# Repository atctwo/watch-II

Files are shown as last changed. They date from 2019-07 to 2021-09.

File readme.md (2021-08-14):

# watch2

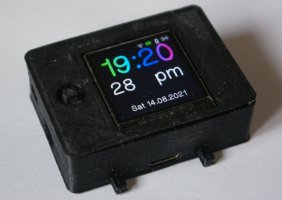
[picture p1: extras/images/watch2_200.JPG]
a picture of the watch


This repository contains the software and design files for my custom smartwatch thing.  The system is built on an ESP32, and the software is written in C++, using ESP-IDF and Arduino.  The software includes a few "apps", which are shown below.

The device uses a custom PCB that holds the ESP32, and all the other electronics that make the system work.  The PCB was designed in KiCad, and the enclosure for the device was made in OpenSCAD.

The system isn't as powerful as existing smartwatches, but it was a really great way for me to learn a lot of electronics and programming concepts and tools.  This isn't supposed to be a marketable product, but a proof of concept thing, and a way for me to develop my skills.  This repository is here as a kind of archive to show the level my skills are at at time of writing, and hopefully as a thing to look back on and learn from.

|  Watch Face |  Settings |  Calculator | Stopwatch |
|---|---|---|---|
|  Timer |  Alarms |  File Browser |  Notepad (read only) |
|  IR Remote |  Image Viewer |  Weather |  Wikipedia |
|  Quiz |  Music Player |  Internet Radio |  BLE Remote |
|  Sensor Thing |  Tetris |  Snek 2 |  NES | 

# Project Structure

- `components` ESP-IDF components
- `design_files` KiCad files for the schematic and PCB
- `docs` documentation for the system (see `docs/readme.md` for more detail)
- `extras` other stuff like icons, data files, and pinout for the original breadboard prototype
- `main` where all the code lives
- `spiffs` data and images for the SPIFFS partition

# Build Instructions

These are some rough instructions for installing and flashing the software on to an ESP32 board.  These steps are mainly aimed for Linux systems.

1. make sure the latest commit of ESP-IDF is installed and setup (this software is currently using commit [1d7068e](https://github.com/espressif/esp-idf/tree/1d7068e4be430edd92bb63f2d922036dcf5c3cc1))
2. `git clone` this repository somewhere - `git clone https://github.com/atctwo/watch-II.git`
3. `cd` into the project directory
    - then run these commands:
    ```
    chmod +x install_libraries.sh
    ./install_libraries.sh
    ```
    - this script automatically clones all of the submodules that the system depends on, then makes any neccessary modifications
4. use `idf.py menuconfig` to tell ESP IDF the flash size of the ESP32 you are using
    - go to `Serial flasher config → Flash size` and select the right flash size (i've only created partition files for 8MB and 16MB at the minute)
    - go to `Partition table → Custom partition CSV file` and enter either `partitions_8mb.csv` or `partitions_16mb.csv`
5. to build the software, run `idf.py build`, and to write the built firmware to an ESP32 board, run `idf.py flash` (see the [ESP-IDF documentation](https://docs.espressif.com/projects/esp-idf/en/latest/esp32/api-guides/build-system.html#idf-py) for more detail on these commands)
6. next, flash an SPIFFS image to the device
    - to do that from the root of the repository, call one of these commands depending on what flash size your ESP32 has:
    ```bash
    # if you're using an 8 MB flash
    esptool.py --port /dev/ttyUSB0 write_flash 0x340000 spiffs/spiffs_8mb.bin  

    # if you're using a 16 MB flash
    esptool.py --port /dev/ttyUSB0 write_flash 0xE20000 spiffs/spiffs_16mb.bin  
    ```
    - more info on how SPIFFS is used can be found at [spiffs/readme.md](spiffs/readme.md)

# Credits
- *lots* of external libraries are used.  the details of these libraries can be found at [`docs/notes/libraries.md`](docs/notes/libraries.md)
- Most app icons are part of the [Papirus Icon Theme](https://github.com/PapirusDevelopmentTeam/papirus-icon-theme)
- Some icons made by [Icongeek26](https://www.flaticon.com/authors/icongeek26) from [Flaticon](https://www.flaticon.com/).
- The weather icons were designed by [Ian Amaral](https://dribbble.com/shots/5446697-Material-Design-inspired-weather-icons).
- The settings icon used in the IR Remote app is the one used by the Windows 10 Settings app.
- The icon used for the internet time button is [time zone](https://thenounproject.com/term/time-zone/2406165/) by Delwar Hossain from the Noun Project.
- The default font used is [HelvetiHand](https://www.dafont.com/helvetihand.font) by [Billy Snyder](https://www.dafont.com/billy-snyder.d4452).  It is modified slightly to add a ™ symbol.
- [Playing Cards](http://byronknoll.blogspot.com/2011/03/vector-playing-cards.html) by byronknoll

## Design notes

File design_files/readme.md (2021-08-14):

# watch 2 Design Files

This folder has a few different subfolders, explained below.  The schematic and PCB for the watch were designed using KiCad.  All of the development on the current form of the schematic + PCB takes place in the `watch2_board` folder.  The case for the watch was designed in OpenSCAD, and was designed to be 3D printed.  The rest of the folders are kept for archival purposes.

- `projects_are_a_bad_idea` an old 1.27mm pitch ESP32 breakout board
- `watch2` an old proof-of-concept version of the watch2 board design 
- `watch2_board` the current version of the board design
- `watch2_case` the case for the watch

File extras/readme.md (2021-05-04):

# Extras

- `icons` where most of the system icons are kept.  the actual code loads the icons from SPIFFS.  the icons used to generate the SPIFFS image are stored under `/spiffs/data`, meaning that this folder might not be completely up-to-date (or well organised)
- `images` some test images that were used at one point
- `i2s mic samples` and `i2s mic samples scaled` i can't remember what these were used for
- `imageconverter.py` a python script to convert a image (eg: png, jpg) to an RGB565 array for drawing to a TFT (most of the system icons are now loaded from SPIFFS as pngs)
- `ir.json` sample IR Remote profile for the IR Remote app
- `pinout.txt` a really old pinout for the original breadboard prototype
- `pinout.xlsx` a much more up to date pinout for the original breadboard prototype
- `Setup_watch2.h` setup file for TFT_eSPI (this is installed automatically by `install_libraries.sh`)

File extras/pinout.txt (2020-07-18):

GPIO	Direction	Usage
0	in		bootstrap pin / screenshot
1	out		tx
2	out		led pin
3	in		rx
4	out		sd chip select
5	out		tft chip select
6			internal spi flash
7			internal spi flash
8			internal spi flash
9			internal spi flash
10			internal spi flash
11			internal spi flash
12	out		ir pin
13	out		torch
14	out		tft backlight
15			<free>
16	in		internal spi ram / ir receive pin
17			internal spi ram
18	out		vspi clk
19	in		vspi miso
20			nc
21	out		vspi rst
22	out		tft dc
23	out		vspi mosi
24			nc
25	out		i2s dout
26	out		i2s lrc
27	out		i2s clock
28			nc
29			nc
30			nc
31			nc
32	in		dpad left
33	in		dpad up
34	in only		battery divider
35	in only		dpad right
36	in only		dpad enter
37			nc
38			nc
39	in only		dpad down

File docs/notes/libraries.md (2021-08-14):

# watch2 libraries

watch 2 depends on lots of different code libraries.  Most of them are Arduino or C/C++ libraries that are included as Git Submodules, although some of them are built into the Arduino ESP32 core (which is included as an ESP-IDF component).  While most libraries will work fine without any modification, some libraries have to be tweaked a bit for watch 2 to be able to work with them.  This page lists each of the libraries that watch2 depends on, and what modifications have to be made.

Most of the required libraries are `#include`d in `main/src/watch2.h`, although libraries that are only required by one app will probably only be `#include`d in the code for that app.

To automatically install and set up each of the libraries, and the Arduino ESP32 Core, you can use the script included in the root of the repository called `install_libraries.sh`.  This will update the submodules, and copy and modify files of libraries that need to be modified.  You can manually update the repository's submodules by running `git submodule update --recursive --init` in the root of the repository.

## Libraries

### STD and STL libraries
These are included as part of the compiler, so you don't have to provide these.  They are just listed here for completion.
- `stdio.h`
- `stdint.h`
- `time.h`
- `sys/time.h`
- `sys/cdefs.h`
- `string`
- `algorithm`
- `functional`
- `stack`
- `map` and `unordered_map`

### built in to ESP-IDF and the Arduino ESP32 Core
These libraries are either part of the ESP-IDF SDK (and thus don't need manually installed), or are part of the Arduino ESP32 Core (which does need installed, but it's included as a submodule, so it will be installed when you run `git submodule update`).
- SPI library (`SPI.h`)
- I2C library (`Wire.h`)
- ESP32 FS library (`FS.h`)
- SD library (`SD.h`)
- WiFi library (`WiFi.h`)
- Wifi secure client library (`WiFiClientSecure.h`)
- HTTP client library (`HTTPClient.h`)
- ESP32 Preferences library (`Preferences.h`)
- [cJSON](https://github.com/DaveGamble/cJSON) (not Arduino or ESP32 specific, but bundled with the ESP32 core)

### external libraries
You will have to install these libraries yourself, although they are included as Git submodules to make installation really easy.
- [TFT_eSPI](https://github.com/Bodmer/TFT_eSPI) by Bodmer
- [JC_Button](https://github.com/JChristensen/JC_Button) by JChristensen
- [Time](https://github.com/PaulStoffregen/Time) by Paul Stoffregen
- [TimeAlarms](https://github.com/PaulStoffregen/TimeAlarms) by Paul Stoffregen
- [ESP32 BLE Keyboard](https://github.com/T-vK/ESP32-BLE-Keyboard) by T-vK
- [ESP32-audioI2S](https://github.com/schreibfaul1/ESP32-audioI2S) by schreibfaul1
- [Adafruit BusIO](https://github.com/adafruit/Adafruit_BusIO) by Adafruit
- [Adafruit MCP23008](https://github.com/adafruit/Adafruit-MCP23008-library) by Adafruit
- [Adafruit LC709203F](https://github.com/adafruit/Adafruit_LC709203F) by Adafruit
- [Adafruit MCP9808](https://github.com/adafruit/Adafruit_MCP9808_Library) by Adafruit
- [Adafruit Unified Sensor Driver](https://github.com/adafruit/Adafruit_Sensor) by Adafruit
- [Adafruit SHTC3](https://github.com/adafruit/Adafruit_SHTC3) by Adafruit
- [csscolorparser](https://github.com/mapbox/css-color-parser-cpp) by Dean McNamee and Konstantin Käfer
- [gumbo-parser](https://github.com/google/gumbo-parser) by Google
- [tinyexpr](https://github.com/codeplea/tinyexpr) by codeplea
- [tinywav](https://github.com/mhroth/tinywav) by mhroth
- [libtris](https://github.com/atctwo/libtris) by atctwo
- [snake-game](https://github.com/atctwo/snake-game) by atctwo

### included with the repository
You won't have to manually install these libraries, because they are directly included with the repository.

The system uses two of nothings' stb libraries (https://github.com/nothings/stb), specifically stb_image.h and stb_image_resize.h.  stb_image was modified slightly to shut the compiler up.  The modified version is included with the source.

HTML character decoding is performed by the [`entities` library](https://stackoverflow.com/a/1082191), by cggaertner.

The NES Emulator is built around [agnes](https://github.com/kgabis/agnes).

The system uses a fork of [IRremote](https://github.com/ExploreEmbedded/Arduino-IRremote) that adds ESP32 send support that was never merged back into the original IRremote.  This fork has been modified to allow the IR receiver to be disabled.  The original IRremote has now added ESP32 send support, and IR receiver disable support, although I have yet to get ESP32 IR send working with the system.

A modified version of [ds1337](https://github.com/richard-clark/ds1337) by Richard Clark is included with the repository.

## Modifications

These are the modifications you need to make to some of the libraries to get watch2 to work with them.  The system will still compile if you don't perform these modifications, but you will need to modify them to match with the exact hardware that you are using.  The modifications listed below are specific to the watch 2 hardware that the system is being developed for, so if you are trying to get watch 2 running on a different board, you should see the documentation for the config files, and configure them to work with the hardware you are using.

Most of these modifications are made automatically by `install_libraries.sh`

### Time

The file `Time.h` was removed to avoid conflicts with the STD library `time.h`.

### Arduino-IRremote

The system uses a fork of IRRemote that adds ESP32 support (https://github.com/ExploreEmbedded/Arduino-IRremote).  Because this fork is included directly in the repository, and not as a submodule, you don't have to make these changes yourself (but they are listed here for completion).  

In the file boarddefs.h, the value of TIMER_PWM_PIN (line 565) was changed from 5 to 4, and the value of TIMER_CHANNEL (line 563) was changed from 1 to 0.  The following method was added at line 159 of irRecv.cpp:
```c++
void IRrecv::disableIRIn() {

#ifdef ESP32
    timerEnd(timer);
    timerDetachInterrupt(timer);
#endif 

}
```
A method prototype was also added at line 180 of IRRemote.h:
```c++
171 class IRrecv
172 {
173 	public:
174 		IRrecv (int recvpin) ;
175 		IRrecv (int recvpin, int blinkpin);
176 
177 		void  blink13    (int blinkflag) ;
178 		int   decode     (decode_results *results) ;
179 		void  enableIRIn ( ) ;
180 		void  disableIRIn( ) ;
181 		bool  isIdle     ( ) ;
182 		void  resume     ( ) ;
```

### TFT_eSPI

The TFT screen is controlled using Bodmer's wonderful TFT_eSPI library (https://github.com/Bodmer/TFT_eSPI).  This library is configured using a User setup header file in the library's source directory.  The file is cloned in the extras folder of this repo (it's called "Setup_watch2.h").  To configure TFT_eSPI to use this setup file, 
1. copy `Setup_watch2.h` to `main/libraries/TFT_eSPI/User_Setups`
2. modify `main/libraries/TFT_eSPI/User_Setup_Select.h`:
    - uncomment `#include <User_Setup.h>` on line 22
    - add `#include <User_Setups/Setup_watch2.h>` on the line below
    - please make sure that only one User Setup is included in this file

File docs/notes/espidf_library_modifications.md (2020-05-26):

As part of the move to ESP-IDF, some libraries were modified to get the system to compile.  This is a list of the modifications made.

## ESP32 Core Wifi library (`components/arduino/libraries/WiFi`)

These modifications were taken from [this ESP32 Arduino issue](https://github.com/espressif/arduino-esp32/issues/3760#issuecomment-591145500).

### `components/arduino/libraries/WiFi/src/ETH.cpp`, line 196

change
```c++
ip_addr_t dns_ip = dns_getserver(dns_no);
return IPAddress(dns_ip.u_addr.ip4.addr);
```

to

```c++
const ip_addr_t * dns_ip = dns_getserver(dns_no);
return IPAddress(dns_ip->u_addr.ip4.addr);
```

### `components/arduino/libraries/WiFi/src/WiFiSTA.cpp`, line 491

change

```c++
ip_addr_t dns_ip = dns_getserver(dns_no);
return IPAddress(dns_ip.u_addr.ip4.addr);
```

to

```c++
const ip_addr_t * dns_ip = dns_getserver(dns_no);
return IPAddress(dns_ip->u_addr.ip4.addr);
```

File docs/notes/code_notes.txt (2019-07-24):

(1) Time
    During active mode operation, functions from TimeLib.h are used to conveniently handle the time.  These functions operate on an internal
    measure of time kept by the library, and don't touch the measure of time maintained by the ESP32.  This measure can be operated on using
    standard POSIX time functions from time.h and sys/time.h.  To ensure that the time is kept while sleeping, the time kept by TimeLib.h is
    used to set the time kept by the ESP32.  When the device goes to sleep, the ESP32 time is set to the TimeLib.h time, and when the device
    is woken up, the TimeLib.h time is set to the ESP32 time.  I know it's unneccessarily complicated, but shut up.

(2) Preferences
    User settings are stored in non-volatile storage (NVS) using the ESP32 library Preferences.  Some of these settings need to be accessed
    every iteration of the main loop (like timeout settings and theme colour settings).  It would be inefficient to access the settings from
    NVS every iteration, so global variables are used to keep copies of the setting values in RAM, allowing for faster access.  When the
    settings are changed, the global variables are set to the new values, and the NVS instances of the settings are updated.  When the
    system is turned on, the NVS settings are loaded, and are used to set the global variables.

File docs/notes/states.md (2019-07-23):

# watch II state system_states
watch II uses a state system to decide what "app" is currently being executed.  State 0 is in initalisation state, state 1 is the watch face, and state 2 is the state menu.  You don't see anything done by state 0, because it executes once, then changes to state 1.

## Adding system states
One way that you can add your own program to the system is to add your own state.  The other option is to write a Lua script.  If you decide to write a state, you get more control over the hardware, and probably more performance, but you have to recompile the system (which you don't have to do if you write a Lua script), and you have to write the state in C++ (specifically Arduino).

To write a state, open `watch2/states/user_states.cpp`.  You will notice that the file contains a function called `registerUserStates()`.  This function is called during system initialisation, so any code written inside this function is executed.  To add a state, you have to use a system function called `registerState()`.  Its parameters are described below:

```
int registerState(String stateName,
                  const std::function<void()> &stateFunc );

    stateName       The name of the state as shown on the state menu
    stateFunc       The function to be executed when this state is loaded

```
Whenever a state is chosen from the state menu, the state is switched, and the function attributed to that state is executed.  The function is executed in a loop until the state is changed.  So that you know when the state is being executed for the first time, you can use a global variable called `state_init`.  Normally this variable is set to 0 when the state function is being called for the first time, and is set to 1 for each call thereafter.  Note that what you write to the screen on the first call won't be displayed, but every subsequent call will.

You can write a function, and pass it as the argument stateFunc, or you can use a lambda.  Rather than writing a function, and giving it a name, and then passing it to `registerState()`, you can write a function as part of the call to `registerState()`.  This is shown below:

```

// define a function and pass it to registerState
void coolStateFunc()
{
    oled.setCursor(2, 2);
    oled.setTextColor(WHITE);
    oled.println("Hello from this function");
}
registerState("A Cool State, using a defined function", coolStateFunc);

// use a lambda
registerState("A Cool State, using a lambda", [](){
    oled.setCursor(2, 2);
    oled.setTextColor(WHITE);
    oled.println("Hello from this lambda");
});

```

You can read up on lambdas on many C++ tutorial websites.

## Changing states
To switch state, use the function `switchState()`.  It has one parameter, which is the state you want to switch to.  If you are returning to the main menu, switch to state number 2.

The state is specified by a global variable called `state`.  There is noting stopping you manually setting it, but that might be a bad idea.

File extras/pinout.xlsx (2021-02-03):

watch2 pinout guide
by atctwo
 |  |  |  |  |  | ESP32 WROVER
5 way navigation switch |  |  | GND |  | GND |  | GND |  | GND
 |  |  | VCC | I2S LRC | 26 |  | NC |  | 23 | MOSI
A (right) | Enter |  | EN | I2S BLK | 27 |  | NC |  | 22 | DC
 |  | wakeup | 36 | Torch / TMS | 14 |  | 4 | IR LED | 1 | TX
 |  |  | 39 | IR recv/TDI | 12 |  | 0 |  | 3 | RX
B (up) | D (down) |  | 34 |  | GND |  | 2 |  | 21 | reset
 |  | I2S DIN | 35 | SD CS / TCK | 13 |  | 15 | SCL | NC
 |  | SDA | 32 |  | 9 |  | 8 |  | 19 | MISO
C (left) | Common | TFT backlight | 33 |  | 10 |  | 7 |  | 18 | Clock
 |  | I2S DOUT | 25 |  | 11 |  | 6 |  | 5 | TFT CS
https://cdn-shop.adafruit.com/datasheets/SKQUCAA010-ALPS.pdf |  |  |  | GND |  |  |  |  | GP7 | supervisor shutdown
 |  |  |  | VCC |  |  |  |  | GP6
 |  |  |  | Bootstrapping pins |  |  |  |  | GP5
 |  |  |  | Internal SPI pins (don’t use) |  |  |  |  | GP4 | dpad left
 |  |  |  | I2C |  |  |  |  | GP3 | dpad down
 |  |  |  | I2S |  |  |  |  | GP2 | dpad enter
 |  |  |  | VSPI + TFT stuff |  |  |  |  | GP1 | dpad up
 |  |  |  | dpad pins |  |  |  |  | GP0 | dpad right
 |  |  |  | other peripherals |  |  |  |  | MCP23008
 |  |  |  | Serial
 |  |  |  | input only pins

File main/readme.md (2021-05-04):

# watch2 Source Code

Here is a brief description of how the code for watch2 is organised

- `main.cpp` contains the system initialisation code, main loop, and main entry point
- each of the `watch2_*.cpp` files contain the source code for handling a particular subsystem or related functions.  they share one big header file called `watch2.h`
    - `watch2_audio.cpp` contains functions for using the I2S audio subsystem
    - `watch2_battery.cpp` contains functions to query the battery fuel gauge
    - `watch2_bluetooth.cpp` contains functions to interface with the BLE subsystem
    - `watch2_dialogues.cpp` contains functions to draw a few interactive popup dialogues
    - `watch2_drawing.cpp` contains functions for drawing standard things like menus
    - `watch2_files.cpp` contains utility functions for talking to an SD card (these functions are designed to complement the functions in the Arduino SD Library)
    - `watch2_images.cpp` contains functions for decoding and drawing standard image formats (based on `stb_image.h`)
    - `watch2_system.cpp` contains some core system functions
    - `watch2_utility.cpp` contains some miscellaneous utility functions
    - `watch2_wifi.cpp` contains functions for talking to the WiFi subsystem
- the `states` directory contains source files for each of the system's states / apps
- the `libraries` folder contains most of the libraries the system depends on
- the `custom_fonts` folder contains fonts converted to header files that were used by early versions of the system
- the `icons` folder contains monochrome icons converted to byte arrays, used in some parts of the system (RGB565 icons are loaded as PNGs from SPIFFS)
- `root_store.cpp` contains a few TLS root certificates
- `regret.h` and `coolcrab.h` are unused image byte arrays

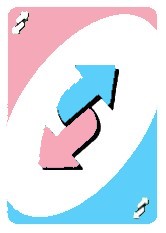
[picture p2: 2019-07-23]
extras/images/pls.jpg

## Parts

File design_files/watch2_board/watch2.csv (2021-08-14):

Reference | Value | Footprint | Datasheet | Availability | Description | MF | MP | Package | Price | AVAILABILITY | DESCRIPTION | PACKAGE | PRICE
BT1 | Battery_Cell | Connector_PinHeader_2.00mm:PinHeader_1x02_P2.00mm_Vertical | ~
U5 | MAX604 | Package_SO:SOIC-8-1EP_3.9x4.9mm_P1.27mm_EP2.29x3mm | http://datasheets.maximintegrated.com/en/ds/MAX603-MAX604.pdf
U2 | MCP73831-2-OT | Package_TO_SOT_SMD:SOT-23-5 | http://ww1.microchip.com/downloads/en/DeviceDoc/20001984g.pdf
D1 | LED | LED_SMD:LED_0805_2012Metric_Castellated | ~
R10 | 1k | Resistor_SMD:R_0805_2012Metric | ~
R9 | 2k | Resistor_SMD:R_0805_2012Metric | ~
R1 | 1k | Resistor_SMD:R_0805_2012Metric | ~
R6 | 1k | Resistor_SMD:R_0805_2012Metric | ~
SW1 | SW_Push | Button_Switch_SMD:SW_SPST_EVQP2 | ~
SW2 | SW_Push | Button_Switch_SMD:SW_SPST_EVQP2 | ~
R7 | 5k1 | Resistor_SMD:R_0805_2012Metric | ~
J1 | USB_C_Receptacle_USB2.0 | Alice's Library:JAE_DX07S016JA1R1500 | https://www.usb.org/sites/default/files/documents/usb_type-c.zip
R8 | 5k1 | Resistor_SMD:R_0805_2012Metric | ~
U4 | MAX16150AUT+T | Package_TO_SOT_SMD:SOT-23-6
U3 | MAX17043G+U | Package_DFN_QFN:DFN-8-1EP_3x2mm_P0.5mm_EP1.7x1.4mm
Q1 | Q_NPN_BCE | Package_TO_SOT_SMD:SOT-23 | ~
R14 | 1k | Resistor_SMD:R_0805_2012Metric | ~
R22 | 1k | Resistor_SMD:R_0805_2012Metric | ~
R5 | 27R | Resistor_SMD:R_0805_2012Metric | ~
R4 | 27R | Resistor_SMD:R_0805_2012Metric | ~
R18 | 1k | Resistor_SMD:R_0805_2012Metric | ~
R17 | 1k | Resistor_SMD:R_0805_2012Metric | ~
D3 | RX | LED_SMD:LED_0805_2012Metric_Castellated | ~
D2 | TX | LED_SMD:LED_0805_2012Metric_Castellated | ~
U1 | FT230XS | Package_SO:SSOP-16_3.9x4.9mm_P0.635mm | https://www.ftdichip.com/Support/Documents/DataSheets/ICs/DS_FT230X.pdf
J5 | Conn_01x03_Male | Connector_PinHeader_2.54mm:PinHeader_1x03_P2.54mm_Vertical | ~
R11 | R | Resistor_SMD:R_0805_2012Metric | ~
R12 | R | Resistor_SMD:R_0805_2012Metric | ~
R13 | R | Resistor_SMD:R_0805_2012Metric | ~
J4 | Conn_01x03_Male | Connector_PinHeader_2.54mm:PinHeader_1x03_P2.54mm_Vertical | ~
R19 | R | Resistor_SMD:R_0805_2012Metric | ~
R20 | R | Resistor_SMD:R_0805_2012Metric | ~
R2 | 4k7 | Resistor_SMD:R_0805_2012Metric | ~
R3 | 4k7 | Resistor_SMD:R_0805_2012Metric | ~
R15 | 1k | Resistor_SMD:R_0805_2012Metric | ~
R16 | 180R | Resistor_SMD:R_0805_2012Metric | ~
R23 | 4k7 | Resistor_SMD:R_0805_2012Metric | ~
R21 | 4k1 | Resistor_SMD:R_0805_2012Metric | ~
C3 | 10nF | Capacitor_SMD:C_0805_2012Metric | ~
C2 | 10uF | Capacitor_SMD:C_0805_2012Metric | ~
J2 | STEMMA QT | Connector_JST:JST_SH_SM04B-SRSS-TB_1x04-1MP_P1.00mm_Horizontal | ~
U7 | ESP32-WROVER | Alice's Library:ESP32-WROVER
J6 | TFT Connector | Connector_PinHeader_2.54mm:PinHeader_1x11_P2.54mm_Vertical | ~
U8 | MAX98357AETE+T | Package_DFN_QFN:QFN-16-1EP_3x3mm_P0.5mm_EP1.7x1.7mm |  | Unavailable | Audio Amp Speaker 1-CH Mono Class-D 16-Pin TQFN EP T/R | Maxim Integrated | MAX98357AETE+T | TQFN-16 Maxim | None
R24 | 680k | Resistor_SMD:R_0805_2012Metric | ~
D4 | LED_TORCH | Alice's Library:MLCAWT-A1-0000-000XE1 | ~
J8 | Torch Connector (daughter board) | Connector_PinHeader_2.54mm:PinHeader_1x02_P2.54mm_Vertical | ~
D5 | LED_IR | Alice's Library:SOD4223X290N | ~
R28 | 100R | Resistor_SMD:R_1812_4532Metric | ~
R31 | 100R | Resistor_SMD:R_1812_4532Metric | ~
LS1 | Speaker | Alice's Library:XDCR_CMT-7525-80-SMT-TR | ~
U9 | TSOP38238 | OptoDevice:Vishay_MINICAST-3Pin | http://www.vishay.com/docs/82491/tsop382.pdf
R25 | 100k | Resistor_SMD:R_0805_2012Metric | ~
R26 | 100k | Resistor_SMD:R_0805_2012Metric | ~
J3 | UART Connector | Connector_PinHeader_1.27mm:PinHeader_1x03_P1.27mm_Vertical | ~
MK1 | SPH0645LM4H-B | Alice's Library:MIC_SPH0645LM4H-B |  |  |  | Knowles | SPH0645LM4H-B |  |  | Unavailable | Mic Mems Digital I2s Omni -26db | SIP-7 Bourns | None
R27 | 10k | Resistor_SMD:R_0805_2012Metric | ~
R29 | 68R | Resistor_SMD:R_0805_2012Metric | ~
C4 | 10uF | Capacitor_SMD:C_0805_2012Metric | ~
C1 | 0.1uF | Capacitor_SMD:C_0805_2012Metric | ~
C5 | 0.1uF | Capacitor_SMD:C_0805_2012Metric | ~
C7 | 0.1uF | Capacitor_SMD:C_0805_2012Metric | ~
C8 | 0.1uF | Capacitor_SMD:C_0805_2012Metric | ~
Q3 | Q_NPN_BCE | Package_TO_SOT_SMD:SOT-23 | ~
R30 | 1k | Resistor_SMD:R_0805_2012Metric | ~
J7 | Torch Connector (main board) | Connector_PinHeader_2.54mm:PinHeader_1x02_P2.54mm_Vertical | ~
Q2 | Q_NPN_BCE | Package_TO_SOT_SMD:SOT-23 | ~
C6 | 0.1uF | Capacitor_SMD:C_0805_2012Metric | ~
U6 | MCP23008-xSS | Package_SO:SSOP-20_5.3x7.2mm_P0.65mm | http://ww1.microchip.com/downloads/en/DeviceDoc/MCP23008-MCP23S08-Data-Sheet-20001919F.pdf
R32 | 1k | Resistor_SMD:R_0805_2012Metric | ~

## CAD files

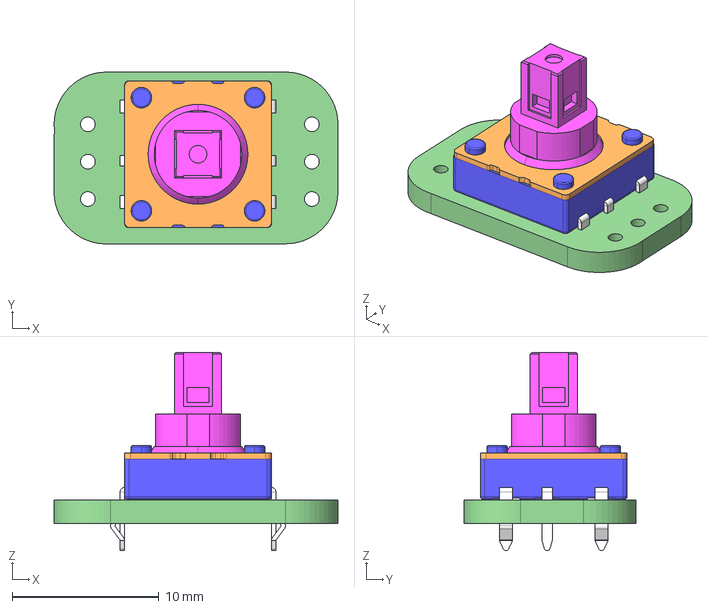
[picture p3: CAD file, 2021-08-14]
design_files/watch2_case/alps-switch.step
19.3 x 11.7 x 13.5 mm

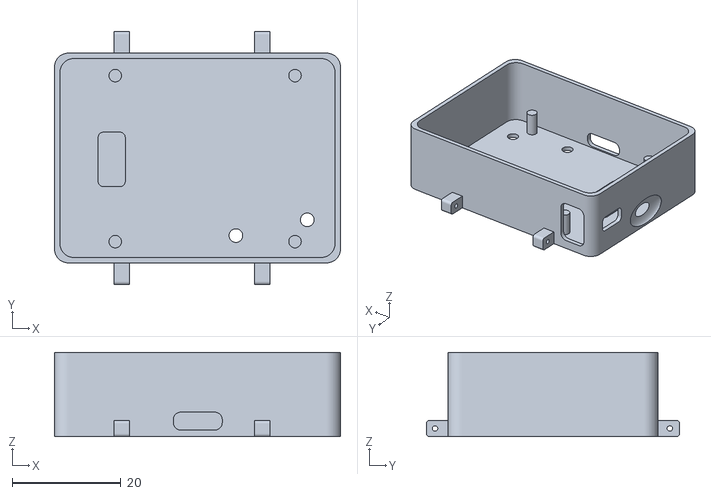
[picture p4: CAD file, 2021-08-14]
design_files/watch2_case/renders/v1-base-3.stl
52.5 x 46.5 x 15.5

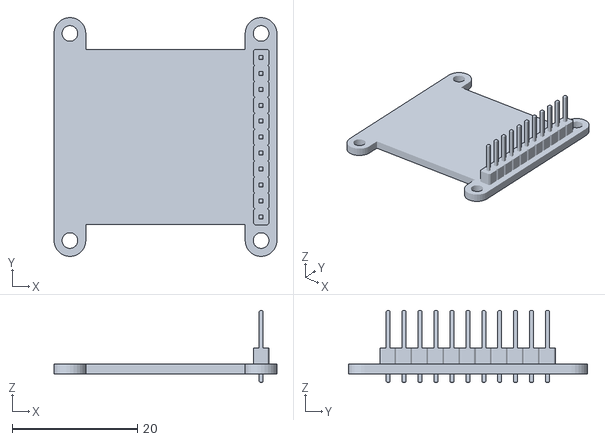
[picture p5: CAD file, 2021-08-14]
design_files/watch2_case/adafruit_1.3_tft.stl
35.6 x 38.1 x 11.5

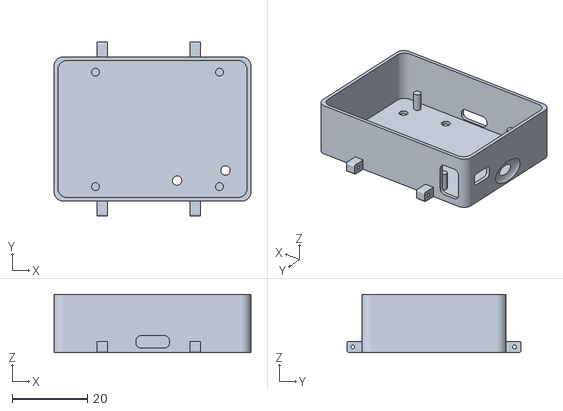
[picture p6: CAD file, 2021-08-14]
design_files/watch2_case/renders/v1-base-2.stl
52.5 x 46.5 x 15.5

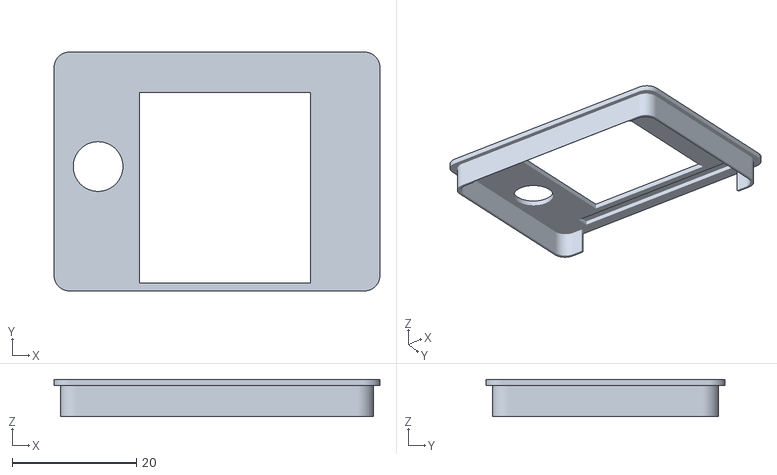
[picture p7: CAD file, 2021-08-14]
design_files/watch2_case/renders/v1-lid-3.stl
52.5 x 38.5 x 6.00

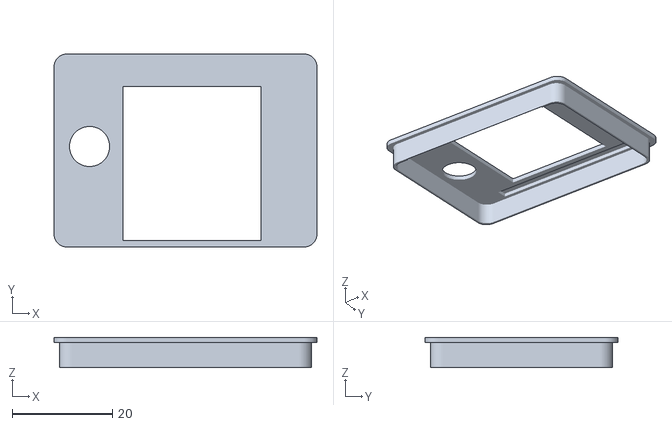
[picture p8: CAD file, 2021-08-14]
design_files/watch2_case/renders/v1-lid-3.1.stl
52.5 x 38.5 x 6.00

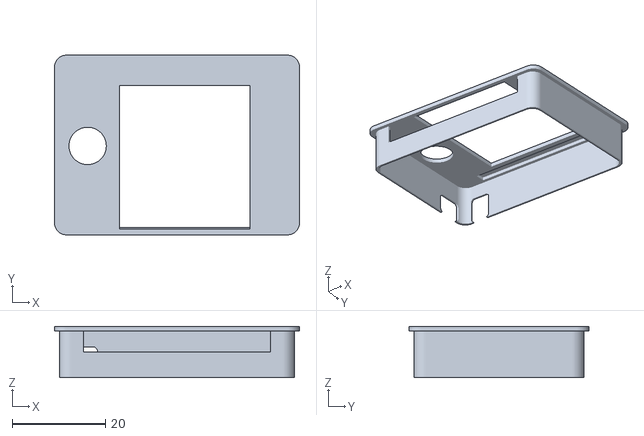
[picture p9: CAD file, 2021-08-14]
design_files/watch2_case/renders/v1.2-lid-1.stl
52.5 x 38.5 x 11.0

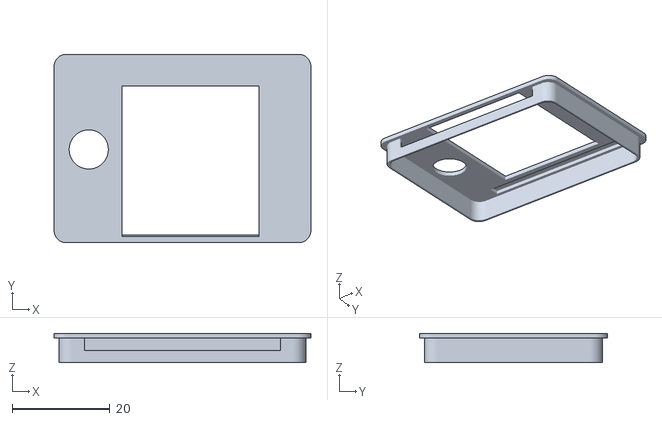
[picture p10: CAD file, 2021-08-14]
design_files/watch2_case/renders/v1-lid-3.3.stl
52.5 x 38.5 x 6.00

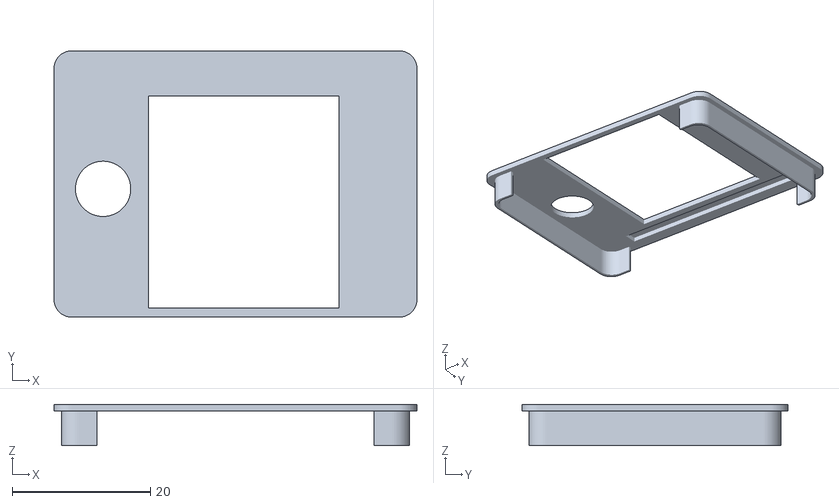
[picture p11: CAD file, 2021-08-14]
design_files/watch2_case/renders/v1-lid-2.stl
52.5 x 38.5 x 6.00

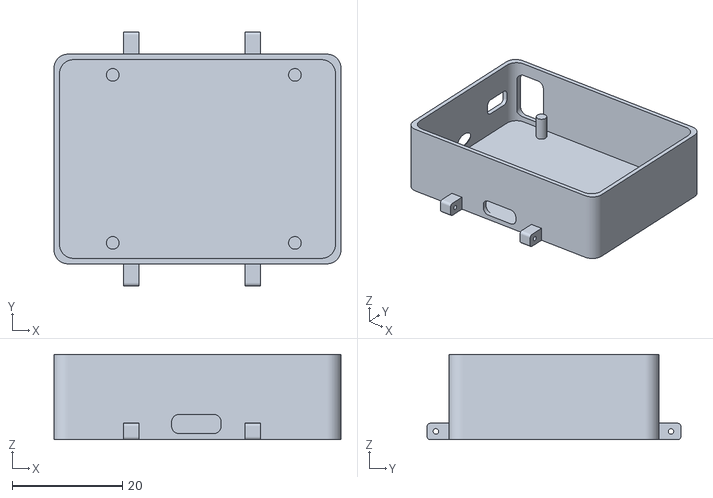
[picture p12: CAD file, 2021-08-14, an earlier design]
design_files/watch2_case/renders/v1-base-1.stl
52.0 x 46.0 x 15.5

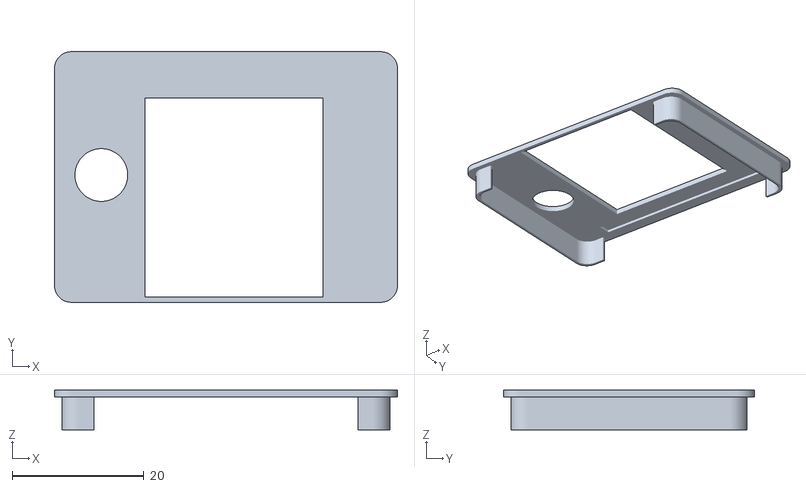
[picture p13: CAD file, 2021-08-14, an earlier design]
design_files/watch2_case/renders/v1-lid-1.stl
52.0 x 38.0 x 6.00

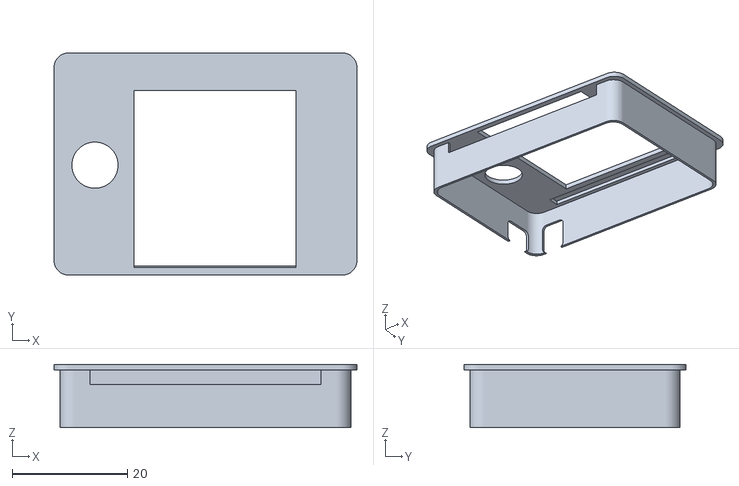
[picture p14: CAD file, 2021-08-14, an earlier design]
design_files/watch2_case/renders/v1.1-lid-1.stl
52.5 x 38.5 x 11.0

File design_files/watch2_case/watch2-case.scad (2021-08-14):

//
//
//  the enclosure for watch2 by atctwo
//  version 1.1
//
//  https://github.com/atctwo/watch-II
//
//


//-------------------------------------
//    includes
//-------------------------------------

include <NopSCADlib/core.scad>
include <NopSCADlib/utils/core/rounded_rectangle.scad>

//-------------------------------------
//    parameters
//-------------------------------------

$fn = 60;

wall_thickness = 1;
post_diameter = 2.3;
post_height = 5;
board_size = [50.5, 36.5, 17 - 2.51];
board_radius = 2.54;
button_hole_diameter = 2.5;

lid_inner_padding = 0.05;
lid_inner_height = 10;
lid_inner_wall_thickness = 0.5;
lid_inner_cutout_width = 40;

screen_hole_size = [27, 29.7, 1.5];
screen_hole_padding = 0.5;
switch_hole_diameter = 8;

springbar_hole_diameter = 1;
springbar_box_size = [2.8, 5, 3];
springbar_box_radius = 0.6;
springbar_separation = 22.45;

show_mainboard = false;
show_alps_switch = false;
show_tft_board = false;

show_lid = false;
show_base = true;
show_lid_inside = true;
show_mainboard_support = false;
show_springbar_holders = true;
show_power_cutout = true;
show_reset_cutout = true;
show_usbc_cutout = true;
show_stemma_cutout = true;
show_io0_cutout = true;
show_led_cutout = true;
show_ir_cutout = false;
show_wall_xz_cutout = false;
show_wall_yz_cutout = false;

// calculations

board_model_offset = [
    -128 + wall_thickness + 1, 
    85 + board_size.y + wall_thickness - 0.4, 
    4.5
];
enclosure_size = [
    board_size.x + (wall_thickness * 2),
    board_size.y + (wall_thickness * 2),
    board_size.z
];
inner_lid_size = [
    enclosure_size.x - (lid_inner_padding * 2) - (wall_thickness * 2),
    enclosure_size.y - (lid_inner_padding * 2) - (wall_thickness * 2),
    lid_inner_height
];

//-------------------------------------
//    boards
//-------------------------------------

if (show_mainboard)
{
    color("cyan")
    translate(board_model_offset)
    import("watch2.stl");
}

if (show_alps_switch)
{
    rotate([0, 0, -90])
    translate([-177.86, 101.4, 10])
    import("alps-switch.stl");
}

if (show_tft_board)
{
    color("Aquamarine")
    {
        translate([132.24, -129.5, 17.4 - 2.51])
        {
            rotate([0, 180, -90])
            import("adafruit_1.3_tft.stl");
        }
    
        translate([14.2, 1.3, 17.4 - 2.51])
        cube([
            screen_hole_size.x,
            screen_hole_size.y,
            screen_hole_size.z
        ]);  
    
    }
    
    
}

//-------------------------------------
//    enclosure
//-------------------------------------

if (show_base)
{

    // walls
    color("RoyalBlue")
    translate([0, 0, wall_thickness])
    difference()
    {
        
        union()
        {
            
            // outer box
            rounded_cube_xy(enclosure_size, board_radius);
            
            // base
            color("CornflowerBlue")
            translate([0, 0, -wall_thickness])
            rounded_cube_xy([enclosure_size.x, enclosure_size.y, wall_thickness], board_radius);

        }
            
        // inner box
        translate([wall_thickness, wall_thickness, -0.1])
        rounded_cube_xy([board_size.x, board_size.y, board_size.z + 0.2], board_radius);

        // usbc cutout
        if (show_usbc_cutout)
        {
            translate([21.8, -0.05, 0.21])
            rounded_cube_xz([9, wall_thickness + 0.1, 3.3], 1.4);
        }
        
        // ir cutout
        if (show_ir_cutout)
        {
            translate([2.8, -0.05, 6.2])
            rounded_cube_xz([4.5, wall_thickness + 0.5, 6.4], 1.4);
        }
        
        // stemma cutout
        if (show_stemma_cutout)
        {
            translate([-0.05, 28.2, 4.2])
            rounded_cube_yz([wall_thickness + 0.1, 6.8, 3.5], 1);
        }
        
        // IO 0 cutout
        if (show_io0_cutout)
        {
            translate([0, 19.4, 2.6])
            scale([0.32, 1.6, 0.9])
            sphere(d=7);
        }
        
        // LED cutout
        if (show_led_cutout)
        {
            translate([2.5, wall_thickness + board_size.y - 0.5, 1])
            rounded_cube_xz([6.5, wall_thickness + 0.51, 9.45], 1.5);
        }
        
        // reset button
        if (show_reset_cutout)
        {
            translate([33.3, 5, -wall_thickness-0.05])
            cylinder(h=wall_thickness+0.1, d=button_hole_diameter);
        }
        
        // power button
        if (show_power_cutout)
        {
            translate([46.4, 7.9, -wall_thickness-0.05])
            cylinder(h=wall_thickness+0.1, d=button_hole_diameter);
        }

        // front cutout
        if (show_wall_xz_cutout)
        {
            translate([0, -2.5, 0])
            cube([55, 5, 20]);
            
            translate([0, 35.5, 0])
            cube([55, 5, 20]);
        }
        
        // side cutout
        if (show_wall_yz_cutout)
        {
            translate([-2.5, 0, 0])
            cube([7, 38, 20]);
        }

    }

    // posts

    // bottom left
    translate([11.155, 3.9, wall_thickness])
    cylinder(h=post_height, d=post_diameter);

    // bottom right
    translate([44.15, 3.9, wall_thickness])
    cylinder(h=post_height, d=post_diameter);

    // top left
    translate([11.155, 34.37, wall_thickness])
    cylinder(h=post_height, d=post_diameter);

    // top right
    translate([44.15, 34.37, wall_thickness])
    cylinder(h=post_height, d=post_diameter);


    // mainboard_support
        if (show_mainboard_support)
        {
            translate([8, 14, 0])
            rounded_cube_xy([5, 10, 4.4], 1);
        }



    // springbar holders

    if (show_springbar_holders)
    {
        difference()
        {
            
            union()
            {
                translate([
                    (board_size.x / 2) - (springbar_separation/2) - (springbar_box_size.x/2) - (springbar_box_size.x/2),
                    -4,
                    0
                ])
                rounded_cube_yz(springbar_box_size, springbar_box_radius);

                translate([
                    (board_size.x / 2) + (springbar_separation/2)  - (springbar_box_size.x/2) + (springbar_box_size.x/2),
                    -4,
                    0
                ])
                rounded_cube_yz(springbar_box_size, springbar_box_radius);
                
            }
            
            translate([
                (board_size.x / 2) - (springbar_separation/1.5),
                -2.4,
                1.51
            ]) rotate([0, 90, 0])
            cylinder(
                h=springbar_separation + (springbar_box_size.x * 3), 
                d=springbar_hole_diameter
            );
                
        }
        
        
        
        difference()
        {
            
            union()
            {
                translate([
                    (board_size.x / 2) - (springbar_separation/2) - (springbar_box_size.x/2) - (springbar_box_size.x/2),
                    board_size.y + 1,
                    0
                ])
                rounded_cube_yz(springbar_box_size, springbar_box_radius);

                translate([
                    (board_size.x / 2) + (springbar_separation/2)  - (springbar_box_size.x/2) + (springbar_box_size.x/2),
                    board_size.y + 1,
                    0
                ])
                rounded_cube_yz(springbar_box_size, springbar_box_radius);
                
            }
            
            translate([
                (board_size.x / 2) - (springbar_separation/1.5),
                board_size.y + 4.2,
                1.51
            ]) rotate([0, 90, 0])
            cylinder(
                h=springbar_separation + (springbar_box_size.x * 3), 
                d=springbar_hole_diameter
            );
                
        }
    }

}
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

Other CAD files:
design_files/watch2_case/renders/v1-base-4.stl
design_files/watch2_case/renders/v1-lid-3.2.stl
design_files/watch2_case/renders/v1.2-base-1.stl
design_files/watch2_case/renders/v1.1-base-1.stl
design_files/watch2_case/roundedcube.scad
design_files/watch2_case/alps-switch.stl

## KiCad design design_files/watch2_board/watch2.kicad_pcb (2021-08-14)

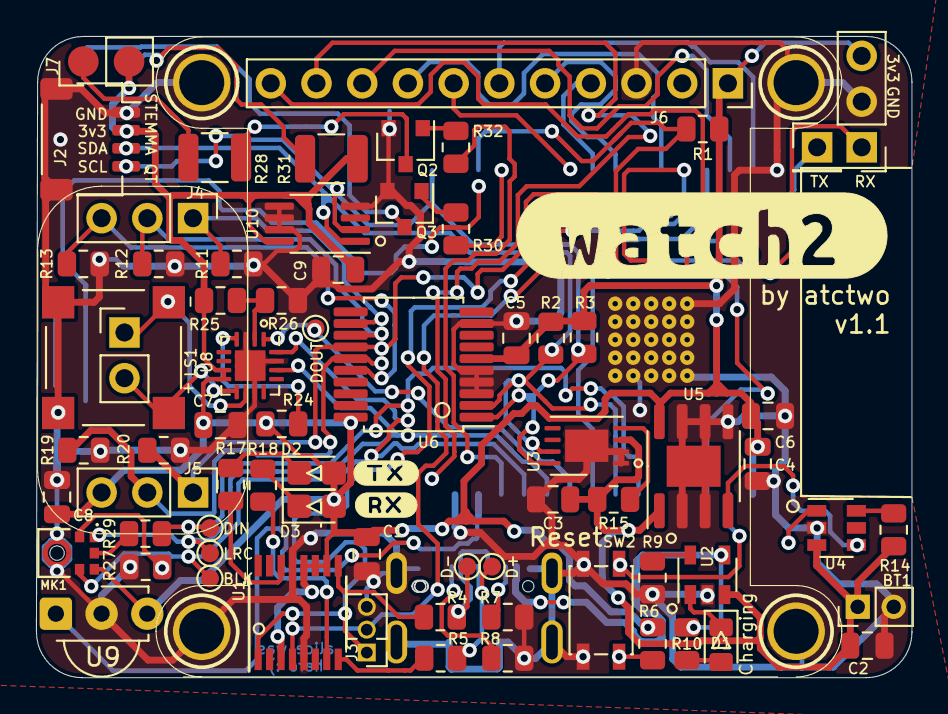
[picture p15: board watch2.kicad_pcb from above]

Board: 2 copper layers, 48.6 x 35.6 mm, 78 parts (0 on the bottom side), 57 nets.

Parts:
BLK: TestPoint_Pad_D1.0mm
BT1: Battery_Cell; PinHeader_1x02_P2.00mm_Vertical
C1, C3, C5, C6, C7, C8, C9: 0.1uF; C_0805_2012Metric
C2, C4: 10uF; C_0805_2012Metric
D1: LED; LED_0805_2012Metric_Castellated
D2: TX; LED_0805_2012Metric_Castellated
D3: RX; LED_0805_2012Metric_Castellated
D5: LED_IR; SOD4223X290N
D+: TestPoint_Pad_D1.0mm
D-: TestPoint_Pad_D1.0mm
DIN: TestPoint_Pad_D1.0mm
DOUT: TestPoint_Pad_D1.0mm
IO0: Panasonic_EVQPUJ_EVQPUA
J1: USB_C_Receptacle_USB2.0; JAE_DX07S016JA1R1500
J2: STEMMA QT; JST_SH_SM04B-SRSS-TB_1x04-1MP_P1.00mm_Horizontal
J3: UART Connector; PinHeader_1x03_P1.27mm_Vertical
J4, J5: Conn_01x03_Male; PinHeader_1x03_P2.54mm_Vertical
J6: TFT Connector; PinSocket_1x11_P2.54mm_Vertical
J7: Torch Connector (main board); PinHeader_1x02_P2.54mm_Vertical
LRC: TestPoint_Pad_D1.0mm
LS1: Speaker; XDCR_CMT-7525-80-SMT-TR
MK1: SPH0645LM4H-B; MIC_SPH0645LM4H-B
Q2, Q3: Q_NPN_BCE; SOT-23
R1, R6, R10, R14, R17, R18: 1k; R_0805_2012Metric
R2, R3: 4k7; R_0805_2012Metric
R4, R5: 27R; R_0805_2012Metric
R7, R8: 5k1; R_0805_2012Metric
R9: 2k; R_0805_2012Metric
R11, R12, R13, R19, R20: R; R_0805_2012Metric
R15, R27: 10k; R_0805_2012Metric
R24: 680k; R_0805_2012Metric
R25, R26: 100k; R_0805_2012Metric
R28, R31: 100R; R_1210_3225Metric
R29: 68R; R_0805_2012Metric
R30, R32: 330R; R_0805_2012Metric
SW2, SW2#2: SW_Push; SW_SPST_EVQP2
SW3: Power Button; SW_SPST_EVQP2
Speaker: PinHeader_1x02_P2.54mm_Vertical
U1: FT230XS; SSOP-16_3.9x4.9mm_P0.635mm
U2: MCP73831-2-OT; SOT-23-5
U3: LC709203FQH-01TWG; WDFN-8-1EP_4x3mm_P0.65mm_EP2.4x1.8mm
U4: MAX16150AUT+T; SOT-23-6
U5: MAX604; SOIC-8-1EP_3.9x4.9mm_P1.27mm_EP2.29x3mm
U6: MCP23008-xSS; SSOP-20_5.3x7.2mm_P0.65mm
U7: ESP32-WROVER
U8: MAX98357AETE+T; QFN-16-1EP_3x3mm_P0.5mm_EP1.7x1.7mm
U9: TSOP38238; Vishay_MINICAST-3Pin
U10: MCP9808_MSOP; MSOP-8_3x3mm_P0.65mm
U$7, U$8, U$9, U$10: MOUNTINGHOLE2.5; MOUNTINGHOLE_2.5_PLATED

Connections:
+3V3: C1.1, C4.1, C5.1, C6.1, C7.1, C8.1, C9.1, D2.2, D3.2, J2.2, J5.3, J6.1, J7.2, MK1.5, R1.1, R2.1, R3.1, R6.1, R24.1, R25.1, R31.2, U1.3, U1.10, U1.11, U1.12, U5.8, U6.6, U6.20, U7.2, U8.7, U8.8, U9.3, U10.8
+5V: BT1.1, C2.1, C3.1, R14.1, R15.1, U2.3, U3.3, U4.3, U5.1
DPAD_DOWN: J5.2, R19.1, U6.15
DPAD_ENTER: J5.1, R20.1, U6.14, U7.4
DPAD_LEFT: J4.3, R13.1, U6.16
DPAD_RIGHT: J4.1, R11.1, U6.12
DPAD_UP: J4.2, R12.1, U6.13
ESP_EN: R6.2, SW2.1, SW2#2.1, U7.3
ESP_IO0: IO0.1, R1.2, U7.25
ESP_RX: J3.1, U1.1, U7.34
ESP_TX: J3.2, U1.4, U7.35
GND: BT1.2, C1.2, C2.2, C3.2, C4.2, C5.2, C6.2, C7.2, C8.2, C9.2, IO0.2, J1.S1, J1.S4, J2.1, J2.MP, J3.3, J6.3, MK1.3, Q2.2, Q3.2, R7.1, R8.1, R9.2, R11.2, R12.2, R13.2, R19.2, R20.2, R26.2, R27.1, SW2.2, SW2#2.2, SW3.2, U1.5, U1.13, U2.2, U3.1, U3.2, U3.9, U4.2, U5.2, U5.3, U5.5, U5.6, U5.7, U6.3, U6.4, U6.5, U6.9, U7.1, U7.15, U7.38, U7.39, U8.3, U8.11, U8.15, U8.17, U9.2, U10.4, U10.5, U10.6, U10.7, U$7.P$1, U$8.P$1, U$9.P$1, U$10.P$1
I2C_SCL: J2.4, R3.2, U3.8, U6.1, U7.23, U10.2
I2C_SDA: J2.3, R2.2, U3.7, U6.2, U7.8, U10.1
I2S_BLK: BLK.1, MK1.4, U7.12, U8.16
I2S_DIN: DIN.1, R29.2, U7.7
I2S_DOUT: DOUT.1, U7.10, U8.1
I2S_LRC: LRC.1, MK1.1, U7.11, U8.14
IR_RECV: U7.14, U9.1
LED_IR: R30.2, U7.26
LED_TORCH: R32.2, U7.13
unnamed: D1.1, U2.1
unnamed: D1.2, R10.1
unnamed: D2.1, R17.1
unnamed: D3.1, R18.1
unnamed: D5.1, Q3.3
unnamed: D5.2, R31.1
unnamed: R10.2, U2.4
unnamed: J7.1, R28.1
unnamed: LS1.1, LS1.N, Speaker.1, U8.10
unnamed: LS1.2, LS1.P, Speaker.2, U8.9
unnamed: MK1.2, R27.2
unnamed: MK1.6, R29.1
unnamed: Q2.1, R32.1
unnamed: Q2.3, R28.2
unnamed: Q3.1, R30.1
unnamed: R4.1, U1.9
unnamed: R5.1, U1.8
unnamed: R9.1, U2.5
unnamed: R14.2, U4.6
unnamed: R15.2, U3.4
unnamed: R17.2, U1.14
unnamed: R18.2, U1.7
unnamed: R24.2, U8.4
unnamed: R25.2, R26.1, U8.2
unnamed: SW3.1, U4.1
unnamed: U4.4, U5.4
SD_CS: J6.10, U7.16
TFT_BL: J6.11, U7.9
TFT_CLOCK: J6.4, U7.30
TFT_CS: J6.7, U7.29
TFT_DC: J6.9, U7.36
TFT_MISO: J6.5, U7.31
TFT_MOSI: J6.6, U7.37
TFT_RESET: J6.8, U7.33
USB_D+: D+.1, J1.6, J1.7, R5.2
USB_D-: D-.1, J1.5, J1.8, R4.2

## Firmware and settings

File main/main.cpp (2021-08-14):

#define SPI_SPEED SD_SCK_MHZ(4)
#include "freertos/FreeRTOS.h"
#include "freertos/task.h"
#include "esp_task_wdt.h"
#include "esp_bt.h"
#include "watch2.h"
#include "icons/small_icons.h"

// esp-idf logging tags
#define TAG_INIT        "watch2-init"
#define TAG_LOOP        "watch2-loop"

////////////////////////////////////////
// setup function
////////////////////////////////////////

void setup() {

    //set cpu Frequency
    //setCpuFrequencyMhz(80);

    // time for cpu to start up
    vTaskDelay(500);

    //begin serial
    Serial.begin(115200);
    ESP_LOGI(TAG_INIT, "\n\nwatch2 version %d\n", WATCH_VER);

    // set up psram
    Serial.println("setting up psram");
    psramInit();
    if (psramFound()) Serial.println("initalised psram");
    else Serial.println("failed to init psram");
    Serial.println("done");

    //set up oled
    ESP_LOGD(TAG_INIT, "setting up display: ");
    digitalWrite(cs, LOW);
    watch2::oled.setAttribute(PSRAM_ENABLE, true);
    watch2::oled.begin();
    watch2::oled.fillScreen(0);
    watch2::oled.writecommand(0x11); // sleep out
    watch2::oled.initDMA();

    watch2::oled.setTextDatum(MC_DATUM);

    //watch2::setFont(MAIN_FONT);
    watch2::oled.setTextSize(3);
    watch2::oled.drawString("loading...", SCREEN_WIDTH/2, (SCREEN_HEIGHT/2) + ((8 * 5) / 2));

    //watch2::setFont(REALLY_BIG_FONT);
    watch2::oled.setTextSize(5);
    watch2::oled.drawString("watch2", SCREEN_WIDTH/2, (SCREEN_HEIGHT/2) - ((8 * 5) / 2));

    watch2::oled.setTextDatum(TL_DATUM);
    watch2::oled.setTextSize(1);
    ESP_LOGD(TAG_INIT, "done");

    // configure gpio data direction registers
    pinMode(12, OUTPUT);
    pinMode(cs, OUTPUT);
    pinMode(sdcs, OUTPUT);
    pinMode(tftbl, OUTPUT);
    pinMode(BATTERY_DIVIDER_PIN, INPUT);
    pinMode(IR_SEND_PIN, OUTPUT);

    digitalWrite(cs, LOW);
   digitalWrite(sdcs, HIGH);


    // set cJSON hooks
    ESP_LOGD(TAG_INIT, "setting up cJSON hooks: ");
    cJSON_Hooks memoryHook;

	memoryHook.malloc_fn = ps_malloc;
	memoryHook.free_fn = free;
	cJSON_InitHooks(&memoryHook);
    ESP_LOGD(TAG_INIT, "done");


    //set up time
    ESP_LOGD(TAG_INIT, "setting up time: ");
    if (watch2::ntp_boot_connect) watch2::ntp_boot_connected = false;
    timeval tv;
    gettimeofday(&tv, NULL);
    setTime(tv.tv_sec);

    if (watch2::boot_count == 0)
    {
        setTime(23, 58, 00, 28, 6, 2019);

    }
    ESP_LOGD(TAG_INIT, "done");



    //set up spiffs
    ESP_LOGD(TAG_INIT, "setting up spiffs: ");
    if (!SPIFFS.begin())
    {
        ESP_LOGD(TAG_INIT, "spiffs init failed");
        watch2::spiffs_state = -1;
    }
    else
    {
        ESP_LOGD(TAG_INIT, "initalised spiffs successfully");
        watch2::spiffs_state = 1;
    }
    watch2::setFont(MAIN_FONT);

    // set up i2c
    ESP_LOGD(TAG_INIT, "setting up i2c devices: ");

    ESP_LOGD(TAG_INIT, "\tWire object: ");
    Wire.begin(I2C_SDA, I2C_SCL);
    ESP_LOGD(TAG_INIT, "done");

    Serial.print("\tMCP23008: ");
    if (watch2::mcp.begin(I2C_ADDRESS_MCP23008))
    {

        for (uint8_t i = 0; i < 7; i++) // set channels 0 to 6 as inputs with no pull up
        {
            watch2::mcp.pinMode(i, INPUT);
            watch2::mcp.pullUp(i, LOW);
        }

        watch2::mcp.pinMode(SHUTDOWN_PIN, OUTPUT); // set shutdown pin as an output w/ pull up
        watch2::mcp.pullUp(SHUTDOWN_PIN, LOW);
        watch2::mcp.digitalWrite(SHUTDOWN_PIN, 1);

        ESP_LOGD(TAG_INIT, "done");
    }
    else 
    {
        ESP_LOGD(TAG_INIT, "failed :(");
    }

    ESP_LOGD(TAG_INIT, "\tMCP9808: ");
    if (!watch2::temperature.begin(I2C_ADDRESS_MCP9098)) ESP_LOGW(TAG_INIT, "mcp9808 init failed");
    else 
    {
        watch2::temperature.setResolution(1);  // 0.25°C
        ESP_LOGD(TAG_INIT, "done");
    }

    ESP_LOGD(TAG_INIT, "\tLC709203F: ");
    if (!watch2::fuel_gauge.begin()) ESP_LOGW(TAG_INIT, "LC709203F not found :(");
    else {
        watch2::fuel_gauge.setPackSize(LC709203F_APA_500MAH);
        watch2::fuel_gauge.setAlarmVoltage(3.4);
    }
    ESP_LOGD(TAG_INIT, "done");

    ESP_LOGD(TAG_INIT, "\tDS1337: ");

    // get time from RTC
    uint8_t status;
    struct ds1337_time_t time_thing;

    if (!ds1337_get_status(&status))
    {

        if (status & DS1337_OSC_STOP_FLAG) {
            // Oscillator has stopped; time is invalid
            ESP_LOGW(TAG_INIT, "DS1337 oscillator stopped; time is invalid");
            ds1337_clear_status();
        } else {

            if (ds1337_read_time(&time_thing)) ESP_LOGW(TAG_INIT, "unable to read time from DS1337");
            else {

                ESP_LOGI(TAG_INIT, "setting time from DS1337: %02d:%02d:%02d %02d.%02d.%04d", time_thing.hour, time_thing.minute, time_thing.second, time_thing.day, time_thing.month, time_thing.year);
                setTime(time_thing.hour, time_thing.minute, time_thing.second, time_thing.day, time_thing.month, time_thing.year + 2000);

            }

        }

    }

    ESP_LOGD(TAG_INIT, "done");

    ESP_LOGD(TAG_INIT, "done setting up i2c");

    //set up SD card
    ESP_LOGD(TAG_INIT, "setting up sd card: ");
    digitalWrite(cs, HIGH);
    digitalWrite(sdcs, LOW);
    
    watch2::initSD();

    digitalWrite(cs, LOW);
    digitalWrite(sdcs, HIGH);
    ESP_LOGD(TAG_INIT, "done");
    
    //set up preferences
    ESP_LOGD(TAG_INIT, "setting up preferences: ");
    watch2::preferences.begin("watch2", false);      //open watch II preferences in RW mode
    watch2::timeout = watch2::preferences.getBool("timeout", false);
    watch2::short_timeout = watch2::preferences.getInt("short_timeout", 5000);
    watch2::long_timeout = watch2::preferences.getInt("long_timeout", 30000);
    watch2::themecolour = watch2::preferences.getInt("themecolour", BLUE);
    watch2::trans_mode = watch2::preferences.getUInt("trans_mode", 0);
    watch2::animate_watch_face = watch2::preferences.getBool("animate_time", true);
    watch2::screen_brightness = watch2::preferences.getUInt("brightness", (2^tftbl_resolution) / 2);
    watch2::timezone = watch2::preferences.getUInt("timezone", 0);
    watch2::ntp_wakeup_connect = watch2::preferences.getBool("ntp_wakeup", true);
    watch2::ntp_boot_connect = watch2::preferences.getBool("ntp_boot", true);
    watch2::wifi_wakeup_reconnect = watch2::preferences.getBool("wifi_wakeup", true);
    watch2::wifi_boot_reconnect = watch2::preferences.getBool("wifi_boot", true);
    watch2::wifi_enabled = watch2::preferences.getBool("wifi_en", false);
    watch2::weather_location = watch2::preferences.getString("weather_city", "");
    watch2::timer_music = watch2::preferences.getString("timer_music", "/music/alarms/CLASSI~1.mp3");
    watch2::alarm_music = watch2::preferences.getString("alarm_music", "/music/alarms/Meander.mp3");
    watch2::wfs = watch2::preferences.getString("wfs", "\x0\x0\x0\x0").c_str();
    watch2::preferences.end();
    ESP_LOGD(TAG_INIT, "done");

    //set up buttons
    ESP_LOGD(TAG_INIT, "setting up buttons: ");
    watch2::btn_dpad_up.begin();
    watch2::btn_dpad_down.begin();
    watch2::btn_dpad_left.begin();
    watch2::btn_dpad_right.begin();
    watch2::btn_dpad_enter.begin();
    ESP_LOGD(TAG_INIT, "done");

    //set up torch
    ESP_LOGD(TAG_INIT, "setting up torch: ");
    ledcAttachPin(TORCH_PIN, TORCH_PWM_CHANNEL);
    ledcSetup(TORCH_PWM_CHANNEL, 4000, 8);
    ledcWrite(TORCH_PWM_CHANNEL, 0);
    ESP_LOGD(TAG_INIT, "done");

    //set up tft backlight
    ESP_LOGD(TAG_INIT, "setting up backlight: ");
    ledcAttachPin(tftbl, TFTBL_PWM_CHANNEL);
    ledcSetup(TFTBL_PWM_CHANNEL, 4000, tftbl_resolution);
    ledcWrite(TFTBL_PWM_CHANNEL, 2^tftbl_resolution);
    ESP_LOGD(TAG_INIT, "done");

    //set up top thing
    ESP_LOGD(TAG_INIT, "setting up top thing: ");
    watch2::top_thing.createSprite(SCREEN_WIDTH, watch2::oled.fontHeight() + 2);
    watch2::setFont(MAIN_FONT, watch2::top_thing);
    ESP_LOGD(TAG_INIT, "done");

    // set up icons
    ESP_LOGD(TAG_INIT, "setting up icons: ");

    // the icon maps are dynamically allocated using malloc() and "placement new"s.

    // allocate memory for maps using malloc; specifically allocate memory from PSRAM
    watch2::icons = (std::map<std::string, watch2::imageData>*) heap_caps_malloc(sizeof(std::map<std::string, watch2::imageData>), MALLOC_CAP_SPIRAM | MALLOC_CAP_8BIT);
    watch2::small_icons = (std::map<std::string, std::vector<unsigned char>>*) heap_caps_malloc(sizeof(std::map<std::string, std::vector<unsigned char>>), MALLOC_CAP_SPIRAM | MALLOC_CAP_8BIT);

    //ESP_LOGD(WATCH2_TAG, "spiram %s", (psramFound() ? "found" : "not found"));
    if (!watch2::icons) ESP_LOGW(TAG_INIT, "failed to allocate memory for icons!");
    if (!watch2::small_icons) ESP_LOGW(TAG_INIT, "failed to allocate memory for small icons!");

    // use placement new to construct objects
    new(watch2::icons) std::map<std::string, watch2::imageData>();
    new(watch2::small_icons) std::map<std::string, std::vector<unsigned char>>();

    // copy icons from flash to ram
    fs::File spi_root = SPIFFS.open("/");
    fs::File spi_file = spi_root.openNextFile();
    while(spi_file)
    {
        if ((watch2::file_ext(spi_file.name()).compare("bmp") == 0) || (watch2::file_ext(spi_file.name()).compare("png") == 0)) // the file extension is bmp
        {
            ESP_LOGD(TAG_INIT, "loading \"%s\" as \"%s\"", spi_file.name(), watch2::file_name(spi_file.name(), false).c_str());
            watch2::imageData loaded_icon = watch2::getImageDataSPIFFS(spi_file.name());
            if (loaded_icon.error) ESP_LOGW(TAG_INIT, "\tload error: %s", loaded_icon.error);
            watch2::registerIcon(watch2::file_name(spi_file.name(), false).c_str(), loaded_icon);
        }

        spi_file = spi_root.openNextFile();
    }
    registerSmallIcons();

    ESP_LOGD(TAG_INIT, "done");

    //set up framebuffer
    //watch2::framebuffer.createSprite(100, 100);
    //watch2::setFont(MAIN_FONT, watch2::framebuffer);

    // set up wifi
    ESP_LOGD(TAG_INIT, "setting up wifi...");
    if (watch2::wifi_enabled)
    {
        watch2::enable_wifi(false);
        if (watch2::wifi_boot_reconnect) 
        {
            watch2::enable_wifi();
        }
    }
    ESP_LOGD(TAG_INIT, "done!");

    // set up bluetooth
    ESP_LOGD(TAG_INIT, "setting up bluetooth...");
    esp_bt_mem_release(ESP_BT_MODE_CLASSIC_BT);     // disable classic bluetooth
    ESP_LOGD(TAG_INIT, "done!");



    // set up state menu
    ESP_LOGD(TAG_INIT, "setting up state menu: ");
    if (watch2::boot_count == 0)
    {
        //set selected menu icon to first non-hidden state
        watch2::selected_menu_icon = 0;
        while(1)
        {
            if (watch2::states[watch2::selected_menu_icon].hidden)
            {
                //check next state
                watch2::selected_menu_icon++;
            }
            else break;
        }
    }
    //else selected_menu_icon = states.find(selected_state);
    ESP_LOGD(TAG_INIT, "done");

    // setup i2s sort of
    // ESP_LOGD(WATCH2_TAG, "setting up i2s: ");
    // watch2::uninstall_i2s_driver();
    // ESP_LOGD(WATCH2_TAG, "done!");

    // set up fs icons
    ESP_LOGD(TAG_INIT, "setting up fs icon maps: ");
    watch2::setupFsIcons();
    ESP_LOGD(TAG_INIT, "done");

    // set up audio task
    ESP_LOGD(TAG_INIT, "setting up audio task: ");
    int x = 10;
    xTaskCreatePinnedToCore(watch2::audio_task, "audio", 10000, (void*)x, ESP_TASK_PRIO_MAX - 1, &watch2::audio_task_handle, 1);
    ESP_LOGD(TAG_INIT, "done");

    ESP_LOGD(TAG_INIT, "setting up watch face shortcuts: ");
    for (uint8_t i = 0; i < watch2::states.size(); i++)
    {
        if (watch2::states[i].stateName == "State Menu") 
        {
            ESP_LOGD(TAG_INIT, "state name, ");
            watch2::wfs[3] = i;
        }
        if (watch2::states[i].stateName == "Bluetooth Remote") 
        {
            ESP_LOGD(TAG_INIT, " ble remote, ");
            watch2::wfs[1] = i;
        }
    }
    ESP_LOGD(TAG_INIT, "done");

    //finish up
    watch2::boot_count++;
    ESP_LOGI(TAG_INIT, "setup finished!");

}

////////////////////////////////////////
// loop function
////////////////////////////////////////

void loop() {

    watch2::startLoop();

    //ESP_LOGD(WATCH2_TAG, "capacitive touch on gpio 0: %d", touchRead(0));

    //---------------------------------------
    // run current state
    //---------------------------------------

    if (watch2::timer_trigger_status == 0 && watch2::alarm_trigger_status == 0)
    {
        if ( watch2::state >= watch2::states.size() )
        {
            //dim screen
            uint8_t contrast = 0x0F;
            //watch2::oled.sendCommand(0xC7, &contrast, 1);

            digitalWrite(12, HIGH);

            watch2::oled.setCursor(5, 10);
            watch2::oled.setTextColor(WHITE, BLACK);
            watch2::oled.print("no state has been\nloaded");
            //watch2::oled.drawRGBBitmap(0, 29, coolcrab, 128, 55);
            if (dpad_any_active()) watch2::switchState(0);
        }
        else watch2::states[watch2::state].stateFunc();

    }

    //---------------------------------------
    // handle timers
    //---------------------------------------

    else if (watch2::timer_trigger_status != 0)
    {
        if (watch2::timer_trigger_status == 1 || watch2::forceRedraw)
        {
            //dim screen
            watch2::dimScreen(0, 10);
            watch2::oled.fillScreen(BLACK);

            //get time to display
            time_t duration = watch2::timers[watch2::timer_trigger_id].initial_duration;
            time_t time_left_hrs = floor(duration / 3600);
            time_t time_left_min = floor(duration % 3600 / 60);
            time_t time_left_sec = floor(duration % 3600 % 60);

            //draw message
            watch2::setFont(MAIN_FONT);
            watch2::oled.setTextColor(WHITE, BLACK);
            watch2::oled.setCursor(2, watch2::top_thing_height);
            watch2::oled.println("Time's up");

            watch2::setFont(REALLY_BIG_FONT);
            watch2::oled.setTextColor(watch2::themecolour, BLACK);
            watch2::oled.printf("%02d:%02d:%02d\n", time_left_hrs, time_left_min, time_left_sec);
            //watch2::oled.setFreeFont(&SourceSansPro_Regular6pt7b);

            watch2::setFont(MAIN_FONT);
            watch2::oled.setTextColor(WHITE, BLACK);
            watch2::oled.print("have elapsed.  press any\nkey to continue");

            //brighten screen
            watch2::dimScreen(1, 10);

            // play music
            SD.begin(sdcs, *watch2::vspi, 4000000U);
            watch2::play_music(watch2::timer_music.c_str(), true);

            //set timer trigger status
            watch2::timer_trigger_status = 2;
        }

        watch2::drawTopThing();
        if (dpad_any_active())
        {
            watch2::timer_trigger_status = 0;
            watch2::stop_music();
            watch2::switchState(0);
        }
    }

    //---------------------------------------
    // handle alarms
    //---------------------------------------

    else if (watch2::alarm_trigger_status != 0)
    {

        static bool selected_alarm_action = 0;
        static bool last_time = 0;
        static char text_aaaa[150];
        static int16_t x1, y1;
        static uint16_t w=0, h=0;
        static uint16_t button_y;
        static uint16_t button_w = 60;
        static uint16_t button_h = 60;
        static uint16_t button_r = 7;
        EXT_RAM_ATTR static TFT_eSprite time_sprite = TFT_eSprite(&watch2::oled);
        static bool pause = false;
        //static GFXcanvas1 *canvas_time = new GFXcanvas1(SCREEN_WIDTH, 20);
        //0 - dismiss
        //anything else - sleep

        if (watch2::alarm_trigger_status == 1 || watch2::forceRedraw)
        {
            //dim screen
            watch2::dimScreen(0, 10);
            watch2::oled.fillScreen(BLACK);

            //brighten screen
            watch2::dimScreen(1, 10);

            //set timer trigger status
            watch2::alarm_trigger_status = 2;

            //calculate button y pos
            watch2::setFont(REALLY_BIG_FONT);
            button_y = watch2::top_thing_height + watch2::oled.fontHeight() + (watch2::oled.fontHeight() / 4);

            //set up time buffer
            watch2::setFont(REALLY_BIG_FONT, time_sprite);
            time_sprite.createSprite(SCREEN_WIDTH, watch2::oled.fontHeight());
            time_sprite.fillScreen(BLACK);

            uint16_t split_width = SCREEN_WIDTH / 4;

            //draw dismiss button
            watch2::drawImage((*watch2::icons)["dismiss"], split_width - (button_w / 2), button_y);
            
            //draw snooze button
            watch2::drawImage((*watch2::icons)["bed"], (split_width * 3) - (button_w / 2), button_y);
            
            //draw button text
            watch2::oled.fillRect(0, button_y + button_h + (button_h / 4), SCREEN_WIDTH, watch2::oled.fontHeight(), BLACK);
            watch2::setFont(MAIN_FONT);
            watch2::oled.setTextDatum(TC_DATUM);
            String button = "< Dismiss     Snooze! >";
            watch2::oled.drawString(button, SCREEN_WIDTH / 2, button_y + button_h + (button_h / 4));
            watch2::oled.setTextDatum(TL_DATUM);

            watch2::alarm_trigger_status = 3;  //hack hack hack hack

            // play music
            SD.begin(sdcs, *watch2::vspi, 4000000U);
            watch2::play_music(watch2::alarm_music.c_str(), true);
        }

        if (now() != last_time)
        {
            watch2::setFont(REALLY_BIG_FONT, time_sprite);
            time_sprite.fillRect(0, 0, SCREEN_WIDTH, time_sprite.fontHeight(), BLACK);
            time_sprite.setTextColor(watch2::themecolour, BLACK);
            time_sprite.setCursor(2, 0);
            time_sprite.printf("%02d:%02d:%02d", hour(), minute(), second());
            time_sprite.pushSprite(0, watch2::top_thing_height);
            last_time = now();
        }

        watch2::drawTopThing();

        if (dpad_left_active())
        {
            ESP_LOGD(TAG_LOOP, "i wanna be a girl and i can't type");
            Alarm.write(watch2::alarms[watch2::alarm_trigger_id].alarm_id, watch2::alarms[watch2::alarm_trigger_id].initial_time);
        }
        if (dpad_right_active())
        {
            time_t time_alarm = Alarm.read(watch2::alarms[watch2::alarm_trigger_id].alarm_id);
            time_alarm += watch2::alarm_snooze_time; // if this is added to a time later than 23:55, then the alarm will be set to 24:something
            Alarm.write(watch2::alarms[watch2::alarm_trigger_id].alarm_id, time_alarm);
        }

        if (dpad_left_active() || dpad_right_active())
        {
            time_sprite.deleteSprite();
            watch2::alarm_trigger_status = 0;
            watch2::stop_music();
            watch2::switchState(0);
        }

    }

    watch2::endLoop();
    

}


////////////////////////////////////////
// esp32 entrypoint
////////////////////////////////////////

// this is the main entrypoint for the system when being compiled with ESP-IDF.
// this was stolen from the arduino esp32 core:
// https://github.com/espressif/arduino-esp32/blob/master/cores/esp32/main.cpp

TaskHandle_t loopTaskHandle = NULL;
bool loopTaskWDTEnabled;

void loopTask(void *pvParameters)
{
    setup();
    for(;;) {
        if(loopTaskWDTEnabled){
            esp_task_wdt_reset();
        }
        loop();
        if (serialEventRun) serialEventRun();
    }
}

extern "C" void app_main()
{
    loopTaskWDTEnabled = false;
    initArduino();
    xTaskCreateUniversal(loopTask, "loopTask", 20000, NULL, 1, &loopTaskHandle, CONFIG_ARDUINO_RUNNING_CORE);
}


////////////////////////////////////////
// system functions
////////////////////////////////////////

extern "C"
{
    void vPortCleanUpTCB ( void *pxTCB ) {
        // place clean up code here
        // this isn't actually used.  this is just here to shut the compiler up if freertos is compiled with
        // static allocation enabled (which it isn;t by default, so if you haven't gone out of your way to
        // modify your esp32 core install, then this doesn't really do anything).
        // see https://docs.espressif.com/projects/esp-idf/en/latest/esp32/api-reference/kconfig.html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
        // for the deets.
    }
}

/*
void Adafruit_GFX::drawRainbowBitmap(int16_t x, int16_t y,
  const uint8_t bitmap[], int16_t w, int16_t h,
  uint16_t bg, int phase_difference) {

    int16_t byteWidth = (w + 7) / 8; // Bitmap scanline pad = whole byte
    uint8_t byte = 0;

	float colour_parts = 360 / w;

    startWrite();
    for(int16_t j=0; j<h; j++, y++) {
        for(int16_t i=0; i<w; i++ ) {
            float R, G, B;
            if (!watch2::trans_mode)   watch2::HSVtoRGB(&R, &G, &B, fmodf(((((float) i) * colour_parts) + phase_difference), (float)360.0), 1.0, 1.0);
            else                                            watch2::getHeatMapColor(fmod(((float)i/(float)w) + (phase_difference/360.0), (float)1.0), &R, &G, &B);
            if(i & 7) byte <<= 1;
            else      byte   = pgm_read_byte(&bitmap[j * byteWidth + i / 8]);
            writePixel(x+i, y, (byte & 0x80) ? watch2::oled.color565((int)(R*255.0), (int)(G*255.0), (int)(B*255.0)) : bg);
        }
    }
    endWrite();
}
*/

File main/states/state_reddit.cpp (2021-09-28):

#include "states.h"
#include "base64.h"

enum reddit_post_types {

    REDDIT_POST_UNKNOWN,
    REDDIT_POST_TEXT,
    REDDIT_POST_IMAGE,
    REDDIT_POST_LINK

};

struct reddit_post {

    std::string id;                     // the id of the post
    reddit_post_types post_type;        // the type of post
    std::string title;                  // the title of the post
    std::string selftext;               // the text / main body of the post
    std::string author;                 // the author of the post
    std::string subreddit;              // the subreddit the post was posted in
    std::string url;                    // the url of the post if it is an image or link post
    uint32_t score;                     // the current score of the post
    float upvote_ratio;                 // the ratio of upvotes to downvotes
    uint32_t creation;                  // the date + time the post was created
    bool nsfw;                          // is the post nsfw?
    bool spoiler;                       // is the post a spoiler?
    bool locked;                        // is the post locked?

};

bool got_access_token = false;      // have we got an access token?
std::string access_token = "";      // the access token provided by reddit
uint32_t access_token_exp = 0;      // when the access token will expire
HTTPClient http;

// main menu
uint8_t menu_selected_item = 0;
std::vector<std::string> menu_items = {"Your Feed", "A Subreddit", "Exit"};
uint16_t menu_y = 0;

// post browser
bool subreddit_feed = false;    // if this is true, get the "best" posts instead of ones from a specific subreddit
std::string subreddit_name;     // the name of the subreddit to get posts from
std::string post_sort = "hot";  // how to sort the posts ("hot", "new", "top", "rising")
std::vector<reddit_post> retrieved_posts; // a store of retrived posts
uint8_t selected_post = 0;

// post viewer
reddit_post *viewing_post;
uint8_t viewer_page = 0;
uint8_t last_viewer_page = 255;
uint8_t viewer_post_scroll = 0;
uint8_t viewer_comments_scroll = 0;

// reddit authentication details
// TODO move these to api_keys.json
std::string reddit_username;
std::string reddit_password;
std::string reddit_app_id = "uiWicUkYCzMFSw";
std::string reddit_app_secret = "FWshU_DE-Mk24O93JoddQ7JWMkTisQ";

std::string getAccessToken()
{
    ESP_LOGI(WATCH2_TAG, "[reddit] getting access token");

    if (millis() > access_token_exp)
    {
        ESP_LOGI(WATCH2_TAG, "[reddit] access token expired or doesn't exist, getting new one");
        watch2::wifi_client_secure.setCACert(root_ca_reddit);
        if (http.begin(watch2::wifi_client_secure, "https://www.reddit.com/api/v1/access_token"))
        {
            ESP_LOGD(WATCH2_TAG, "[redit] connected to server");

            String auth = base64::encode(std::string(reddit_app_id + ":" + reddit_app_secret).c_str());
            http.addHeader("Authorization", "Basic " + auth);
            http.addHeader("Content-Type", "application/x-www-form-urlencoded");
            http.setUserAgent("watch2");

            int http_code = http.POST("grant_type=password&username=atctwo&password=Edt6d42!^");
            ESP_LOGI(WATCH2_TAG, "[reddit] http code: %d (%s)", http_code, http.errorToString(http_code));

            if (http_code > 0)
            {
                if (http_code == HTTP_CODE_OK)
                {
                    String res = http.getString();
                    ESP_LOGI(WATCH2_TAG, "response: %s", res.c_str());

                    cJSON *token = cJSON_Parse(res.c_str());
                    access_token = cJSON_GetObjectItem(token, "access_token")->valuestring;
                    access_token_exp = (cJSON_GetObjectItem(token, "expires_in")->valueint * 60) + millis();
                    got_access_token = true;
                    cJSON_free(token);

                    return access_token;
                }
            }
            else ESP_LOGD(WATCH2_TAG, "[reddit] ???");
            
        }
        else
        {
            ESP_LOGW(WATCH2_TAG, "[reddit] failed to connect");
        }

        return "";

    }
    else
    {
        ESP_LOGI(WATCH2_TAG, "[reddit] access token already exists :)");
        return access_token;
    }
}



cJSON *sendAPIgetRequest(std::string endpoint)
{
    ESP_LOGI(WATCH2_TAG, "[reddit] sending api request: %s", endpoint.c_str());

    char *page = (char *) ps_malloc(sizeof(char));
    int lengthHtml = 0;

    watch2::wifi_client_secure.setCACert(root_ca_reddit);
    if (http.begin(watch2::wifi_client_secure, std::string("https://oauth.reddit.com" + endpoint).c_str()))
    {
        ESP_LOGD(WATCH2_TAG, "[redit] connected to server");

        http.addHeader("Authorization", String(std::string("bearer " + getAccessToken()).c_str()));
        http.setUserAgent("watch2");

        int http_code = http.GET();
        ESP_LOGI(WATCH2_TAG, "[reddit] http code: %d (%s)", http_code, http.errorToString(http_code));

        Serial.println("headers:");
        for (int i = 0; i < http.headers(); i++)
        {
            Serial.printf("\t(%d) %s: %s\n", i, http.headerName(i).c_str(), http.header(i).c_str());
        }

        if (http_code > 0)
        {
            if (http_code == HTTP_CODE_OK)
            {

                // response processing code taken from https://learn.upesy.com/en/programmation/psram.html

                // Essaye de récupérer la taille du ficher ( -1 s'il n'y a pas de Content-Length dans l'header)
                int tempLength = http.getSize();
                Serial.println((String) "Content Length :" + tempLength);

                //Stockage de la page dans la PSRAM
                Serial.printf("Adresse mémoire de la page : %p \n", page);

                // Récupère le stream TCP
                WiFiClient *stream = http.getStreamPtr();

                //Initialisation position du buffer dans la PSRAM
                int position = 0;

                uint32_t currentTime = 0;
                uint8_t timeoutArboted = 1;

                // Récupère toute les données du fichier
                while(http.connected() && (tempLength > 0 || tempLength == -1))
                {

                    // Récupère les données disponibles (les données arrivent packets par packets)
                    size_t size = stream->available();
                    if (size){
                        page = (char*) ps_realloc(page, position + size + 1);
                        stream->readBytes(page+position, size);
                        position += size;

                        if (tempLength > 0){
                                tempLength -= size;
                        }
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

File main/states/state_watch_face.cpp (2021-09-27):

#include "states.h"

void state_func_watch_face()
{

    static int last_minute = -1;
    static int last_second = -1;
    static int last_day = -1;
    EXT_RAM_ATTR static TFT_eSprite time_sprite = TFT_eSprite(&watch2::oled);
    EXT_RAM_ATTR static TFT_eSprite second_sprite = TFT_eSprite(&watch2::oled);
    EXT_RAM_ATTR static TFT_eSprite day_sprite = TFT_eSprite(&watch2::oled);
    EXT_RAM_ATTR static char buffer[20];
    uint16_t row_colours[SCREEN_WIDTH];
    uint16_t row_colour = CYAN;
    float r = 0, g = 0, b = 0;
    uint16_t phase_difference = 0;
    static bool sprite_init = false;

    if (watch2::states[watch2::state].variant == 0) //actual watch face
    {

        /*
        //draw introduction message
        watch2::oled.setCursor(2, watch2::top_thing_height);
        watch2::oled.setTextColor(WHITE, BLACK);

        watch2::oled.setTextSize(1);
        watch2::oled.print("The time right now is");
        */

        if (!sprite_init)
        {
            // set up time sprite
            watch2::setFont(REALLY_REALLY_BIG_FONT);
            time_sprite.createSprite(SCREEN_WIDTH, watch2::oled.fontHeight());
            time_sprite.fillScreen(BLACK);
            watch2::setFont(REALLY_REALLY_BIG_FONT, time_sprite);

            // set up seconds buffer
            watch2::setFont(REALLY_BIG_FONT);
            second_sprite.createSprite(SCREEN_WIDTH, watch2::oled.fontHeight());
            second_sprite.fillScreen(BLACK);
            watch2::setFont(REALLY_BIG_FONT, second_sprite);

            // set up date buffer
            watch2::setFont(SLIGHTLY_BIGGER_FONT);
            day_sprite.createSprite(SCREEN_WIDTH, watch2::oled.fontHeight());
            day_sprite.fillScreen(BLACK);
            watch2::setFont(SLIGHTLY_BIGGER_FONT, day_sprite);
            watch2::setFont(MAIN_FONT);

            watch2::last_button_press = millis();
            sprite_init = true;
        }

        // set phase difference
        if (watch2::animate_watch_face) phase_difference = ((millis() % 60000) * 6)/1000;

        // draw time
        draw(second() != last_second, {


            // set up time sprite colour things
            for (int i = 0; i < SCREEN_WIDTH; i++)
            {
                switch(watch2::trans_mode)
                    {
                        case 0: // random
                            //todo

                        case 1: // Gay™
                            watch2::HSVtoRGB(&r, &g, &b, fmodf(((((float) i) * (360 / SCREEN_WIDTH)) + phase_difference), (float)360.0), 1.0, 1.0);
                            row_colour = watch2::oled.color565(r * 255, g * 255, b * 255);
                            break;

                        case 2: // trans
                            watch2::getHeatMapColor( fmod(((float)i/(float)SCREEN_WIDTH) + (phase_difference/360.0), (float)1.0) , &r, &g, &b, {
                                {0.333, 0.804, 0.988},
                                {0.969, 0.659, 0.722},
                                {0.984, 0.976, 0.961},
                                {0.969, 0.659, 0.722},
                                {0.333, 0.804, 0.988}    
                            });
                            row_colour = watch2::oled.color565(r * 255, g * 255, b * 255);
                            break;

                        default:
                            row_colour = CYAN;
                            break;
                    }

                row_colours[i] = row_colour;
            }


        
            // draw minute
            time_sprite.fillScreen(BLACK);
            time_sprite.setTextDatum(MC_DATUM);
            sprintf(buffer, "%02d:%02d", hour(), minute());
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

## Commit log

2019-07-23 idk what i am doing
    [projects_are_a_bad_idea.kicad_pcb, projects_are_a_bad_idea.sch]
2019-08-10 Added basic stopwatch, changed sleep to light sleep
    [esp32_breadboard_breakout.kicad_pcb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]
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2019-08-20 Fixed alarms and sleeping over two days
    Whenever an alarm was set for the next day, and the alarm went off, the
    current time would be later than the alarm time, but the alarm would
    not be paused. This meant that the time until the alarm goes off would
    evaluate as a negative number, and the device would instantly wake up
    when going into sleep. This commit changes the code so that the timer
    wakeup is only set if the alarm time is later than the current time.
2019-08-21 Added torch, screen brightness and ripoff control centre
    Added a control centre thing which can provides quick access to some
    settings from the watch face. It includes sliders for volume (which
    does nothing yet), screen brightness, and torch brightness. It adds
    quick buttons for WiFi and Bluetooth (which also don't do anything yet).
2019-11-22 Added preliminary SD support
    - added light mode to top thing
    - top thing shows sd card mount status
    - added functions to handle mounting an sd card (initSD()) and to read
    the contents of a directory
    - initSD() is called at system startup, when the device is woken up, and
    when the user presses left on the watch face
    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
    [projects_are_a_bad_idea-B_Cu.gbl, projects_are_a_bad_idea-B_Mask.gbs, projects_are_a_bad_idea-B_Paste.gbp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]
2019-12-17 Added file selection dialogue - added a file selection dialogue, which allows the user to pick a file on the sd card - added design files for mainboard
    [watch2.kicad_pcb, watch2.sch]
2019-12-27 started ir remote - added ir remote that loads ir remote profiles from sd card - sd card support is kind of broken, so the ir app is also kind of broken (it's wip) - it loads profiles stored on the s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
    [watch2.h]
2020-01-02 updated code to address members of watch2 directly most of the code in the last commit referenced members of the namespace watch2 indirectly (by using "using namespace watch2;"). the code has updated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
2020-01-09 state menu updated to work w/ tft
    - the state menu now looks ok on the tft
    - state icons have been redesigned, but i was too bored or lazy so
    they don't look very good, and will probably be re-redesigned
    later
    - updated ir remote so that you can actually pick an ir profile. it's
    still quite buggy
    - added an image viewer based on stb_image.h. it loads the entire
    image into memory, so only small images can be displayed
    for now
    - some files i used for making notes have been moved to docs to
    organise the project files a bit better
    - everything now uses a larger font, instead of using the small font
    that the oled used. it uses tft_espi's anti-aliased fonts
    feature, so the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
    [Setup_watch2.h]
2020-01-16 timers, alarms, and fonts - updated timers and alarms. they now look ok - font names can now be set in watch2.h (instead of in the state code that changes fonts)
2020-01-17 updated stopwatch + wip framebuffer - the stopwatch now works with the tft - some code for an experimental framebuffer has added, but it doesn't work very well
    [watch2.h]
2020-01-20 updated calculator to work w/ tft - the calculator now looks lovely-ish - fixed the thing where the watch face fades in twice when waking up from sleep - added code to change the datum of the stopwat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
2020-02-19 broke ir remote - broke the ir remote app. i'm going to rewrite it from scratch - i tried to add support for an ir receiver, but it's also broken
    [watch2.h]
2020-03-01 added working ir remote app - added ir remote app that actually works. the ir remote and receiver modes work (and the serial mode doesn't work yet) - added functions for loading images - ledc channel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
    [state_watch_face.cpp, watch2.h]
2020-03-04 updated alarm + timer complete screens - updated the time up screens for the timer and alarm apps to work with the tft
2020-05-08 i did a lot of things, are you proud of me? - added boot sequence step descriptions over serial (so you can see what's happening when the watch is booting) - removed the #include for Adafruit ImageRe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
    [state_watch_face.cpp, watch2.h]
2020-05-14 added wifi support! - added insane wifi subsystem that might have lots of bugs - wifi button in ripoff control centre now works - wifi settings page - wifi auto reconnect options - when you connect t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
    [state_watch_face.cpp, watch2.h]
2020-05-14 fixed new AP timeout issue
    [watch2.h]
2020-05-15 added wip wikipedia app - added very buggy wikipedia app - cleaned up some serial debugging
    [Setup_watch2.h, watch2.h]
2020-05-20 added quiz app, doesn't do anything - added a quiz app, which was supposed to get questions from the Open Trivia Database (opentdb.com), but I can't get TLS to work properly, so i've just been using 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
    [watch2.h]
2020-05-20 added experimental bluetooth support there is some very basic bluetooth support that enables a BLE HID keyboard using the BleKeyboard Arduino library. it doesn't do anything yet because you can't run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
    [state_watch_face.cpp, watch2.h]
2020-05-26 Ported system to ESP-IDF 3.3.2 The entire system is now set up as an ESP IDF project. It can still use arduino as a base, because it depends on the esp32 arduino core, which is used as an ESPIDF comp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
    [partitions.csv]
2020-05-28 Enabled bluetooth You can now enable bluetooth from the ripoff control centre, but it doesn't work yet. It now doesn't crash when wifi is also enabled, which is why bluetooth was disabled in the firs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
    [state_watch_face.cpp]
2020-05-28 ble kind of works - modified sdkconfig to disable BT classic, which means that BLE sort of works (idk why) - updated ripoff control centre so that the BT icon changes when the BT state changes - fixe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
    [state_watch_face.cpp]
2020-06-08 added interfaces for different audio formats + fixed watch not waking up after sleep (#26)
    [main.cpp, watch2.h]
2020-07-28 added draw macro thing (#31) this macro allows you to automatically call a block of code whenever the screen should be redrawn (ie: on state init, or when forceRedraw is true). this commit also adds 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
    Every drawing code block has been updated to use the macro, so dialo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
    [pinout.xlsx]
2020-07-28 updated IRRemote library + updated ir receiver - updated the system to use the latest version of the Arduino IRRemote library. The system previously used a fork of the library that added esp32 send s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
    [pinout.xlsx]
2020-07-28 updated pinout spreadsheet + ir recv message
    [pinout.xlsx]
2020-07-31 rolled IR library back to fork the latest upstream version of the library breaks IR sending for ESP32 devices
2020-08-01 fixed a bug that broke blank IR buttons this commit stops blank IR buttons mirroring button 0
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2020-08-02 added documentation for most watch2 apis
    [app__icons_8cpp.xml]
2020-08-05 removed docs
    [app__icons_8cpp.xml]
2020-08-05 moved tetris menu function to watch2 api and moved i2s microphone breakout to a different repo
    [projects_are_a_bad_idea.kicad_pcb, projects_are_a_bad_idea.sch]
2020-08-14 updated system to esp-idf-v4.0.1 and added jtag pins to pinout
    [pinout.xlsx]
2020-09-27 more attempting to get music stuff working
    [pinout.xlsx]
2020-10-01 the control centre now shows the weather! - it uses the openweather api - the key for the api is loaded from SPIFFS using a new key loading system - fixed a bug where wifi broke after disabling it - 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
    aaaaaaaaaaaaaaaaaaaaaaaaaaaaa
    i need to sleep 🙃
    [watch2.h]
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2020-10-23 app icons are now loaded from SPIFFS previously, app icons were stored as literals in a .cpp file, and automatically loaded into internal RAM (and took up about 40% of ram). now, images are loaded at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
    [partitions.csv]
2020-11-07 file select menus now have icons!
    [pinout.xlsx]
2020-11-09 sd test is now a file browser is shows you lots of file info like size and times, and you can rename or delete files and i am very tired
2020-11-11 improved audio stuff also fixed some issues with submodules, and ambiguity between the ESP32 SD object and SdFat
    [main.cpp, watch2.h]
2020-11-12 moved dpad pins to external MCP23008 instead of wiring dpad pins to the esp32 (using 5 pins), they are now wired to an MCP23008 i2s io expander. this means that there are now 5 more free pins on the 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
    [pinout.xlsx]
2020-11-18 added internet radio
    [pinout.xlsx]
2020-11-19 added sounds to alarms and timers and fixed a bug where leaving timer and alarm screens would hang the system?
    [main.cpp, watch2.h]
2020-11-20 added method of changing alarm and timer sounds and updated alarm and timer icons
2020-11-22 images are now drawn using dma also, everything now uses arduino's SD library, rather than SdFat, because DMA image drawing seemed to break SdFat for some reason
2020-12-05 added watch face shortcuts
    [main.cpp, state_watch_face.cpp, watch2.h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]
2021-01-05 i did a lot of things - fixed crash when loading games with the nes app - added new pcb that isn't finished yet - pinout changes?
    [pinout.xlsx, watch2.kicad_pcb]
2021-01-05 added support for a lipo fuel gauge also, modified the heat map function to accept a custom heatmap as a parameter
2021-01-06 fixed #45 (sd doesn't work after sleep) and updated documentation on IRRemote modifications
    [watch2_files.cpp]
2021-01-10 added shutdown button
    [pinout.xlsx]
2021-01-10 updated sleep timer time thing i think this fix will prevent large alarm time differences overflowing, making the watch wake up immediately after sleeping sometimes i think i really don't know why th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
    [watch2_system.cpp]
2021-02-03 added the system schematic it's mostly complete, i still need to do a bit of harware stuff to finish the prototype the schematic is based off the breadboard circuit i'm using to test the code
    [pinout.xlsx, watch2.sch]
2021-02-03 actually updated documentation and removed a submodule that didn't exist
    [Setup_watch2.h, watch2.h]
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2021-02-04 ble: added ble hid support to system previously, i was using T-vK's ESP32 BLE Keyboard library (https://github.com/T-vK/ESP32-BLE-Keyboard) to send media key reports over BLE. now, the system impleme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
2021-02-06 added torch + ir stuff to schematic and did some pcb stuff
    [watch2.kicad_pcb, watch2.sch]
2021-02-07 added audio recorder app it doesn't actually record any data yet, it just visualises it
    [watch2.h, watch2_audio.cpp]
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2021-02-08 fixes to audio subsystem the i2s driver is now installed and uninstalled as needed
    [watch2.h, watch2_audio.cpp]
2021-02-09 fixed internet radio stuttering
    [watch2_audio.cpp]
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2021-02-10 added transistors to leds in schematic
    [watch2.sch]
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2021-02-12 created watch2 pcb it's mostly populated and wired up. i haven't checked it yet, and i haven't figured out how to make IO0 externaly pressable yet :)
    [watch2.kicad_pcb, watch2.sch]
2021-02-13 created initial version of the pcb
    [watch2 (copy).kicad_pcb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]
2021-03-08 - switched BLE subsystem to NimBLE (from Bluedroid) using https://github.com/h2zero/esp-nimble-cpp/tree/master - renamed arduino-esp32 component to arduino - increased stack size + task priority for 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
    [main.cpp, watch2.h, watch2_audio.cpp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]
2021-05-04 added i2c device presence checks so that if the devices aren't present for whatever reason, the watch doesn't crash
    [main.cpp, watch2.h]
2021-05-04 added 8mb partition file + spiffs data - added partition file for 8mb flash chips, and renamed existing one to partitions_16mb.csv - added folder to store stuff needed for spiffs - data folder contai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
    [partitions.csv, partitions_16mb.csv, partitions_8mb.csv]
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2021-05-05 fixed #57 and #2
    [main.cpp]
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2021-06-11 switched lipo fuel gauge the system used to use a MAX17043, but they were expensive and hard to buy, so I ended up using the LC709203F. this commit swaps out MAX17043 support for LC709203F support
2021-06-30 i did some things - the commit which added LC709203F support didn't actually add anything, so this commit adds those things - some changes to Wifi logging
    [threads.scad, watch2-case.scad]
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2021-06-30 actually added sensor thing the last commit didn't actually stage any files
    [watch2.h]
2021-07-02 Added + updated some icons - finally fixed watch face icon - added sensors, snake, and cards icons
2021-07-02 Fixed image corruption The function that draws images to the TFT used to use DMA, but for some reason, the images got corrupted very easily. This commit switches to using the standard blocking non-DM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
    [watch2_images.cpp]
2021-07-04 Hopefully fixed Wifi after sleep bug!
    [watch2_system.cpp, watch2_wifi.cpp]
2021-07-04 fixed a few things - the watch no longer thinks every day is Thursday - the watch now doesn't always say it is pm - idle timeout now works again - there is now a bluetooth icon in the top thing - the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
    [state_watch_face.cpp, watch2.h, watch2_dialogues.cpp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]
2021-08-11 added a reddit app - added a reddit client that mostly works - added function to decode image from memory - battery is now read when watch starts - fixed quiz app? - some memory optimisations
    [main.cpp, state_reddit.cpp, state_watch_face.cpp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]
2021-08-14 fixed ir remote bug and made some memory optimisations
    [main.cpp]
2021-08-14 added pcb v2 files
    [watch2-board-outline.kicad_pcb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]
2021-08-14 added pcb v2 files again
    [watch2.kicad_pcb, watch2.sch]
2021-08-14 added watch2 case / enclosure
    [adafruit_1.3_tft.stl, alps-switch.step, alps-switch.stl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]
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
